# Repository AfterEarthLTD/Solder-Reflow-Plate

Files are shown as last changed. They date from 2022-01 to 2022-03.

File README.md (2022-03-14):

# **Solder Reflow Plate**

###### By AfterEarth Ltd

## As Seen On GreatScott! 

This project has recently featured on a DIY or BUY GreatScott! video.

Check it out here - [The Best way to reflow solder? Hot Plate to the rescue! DIY or Buy](https://www.youtube.com/watch?v=QarizoUnRfk)

## UPDATE!!!

Join the [DISCORD!](https://discord.gg/YzhG6FcCRA)

Checkout the new Ver 3.0 design. Very similar to Ver 2.4 but now comes with ATmega4809 as its availability is much better than the 328p at the moment. Code is still in development but the board designs are available in the Board Versions Folder.

## Versions

- 70mm x 50mm (Ver 2.4)
  - 12VDC (5A Minimum)
  - 5.5mm x 2.5mm Barrel Jack
  - 0.91" OLED Display
  - ATmega328p Microprocessor

- 70mm x 50mm (Ver 3.0) **NEW**
  - 12VDC (5A Minimum)
  - 5.5mm x 2.5mm Barrel Jack
  - 0.91" OLED Display
  - ATmega4809 Microprocessor

## About the Project

Like any good nerd does I've been expanding my hobby horizons.
I've gone from breadboard, to perf board, through-hole, to SMD, ever increasing circuit complexity and improving my knowledge.
But I've become frustrated with the difficulty of SMD soldering.
Regular soldering jogs small components and needs lots of flux.
Hot air damages plastics.
Hot plates are expensive and can be big wastes of space.

*"But you're a nerd"* I hear you cry, *"why don't you DIY a solution?"*.

[Electronoobs](https://www.youtube.com/channel/UCjiVhIvGmRZixSzupD0sS9Q) shows a great DIY solution using an old clothes iron hot plate.
You can watch his video [here.](https://www.youtube.com/watch?v=C7blZigaaaA)
Have a go!

While I love this solution, I wanted to develop something smaller and more permanent.
Hence the Solder Reflow Plate was born, a PCB-based, MOSFET controlled heater, perfect for easily reflowing SMD components giving surprisingly professional results. Furthermore, these results are achieved without breaking the bank or taking up an enormous amount of desk space.

And so, this nerd bestows upon the world his project, fully open-source and hackable.
Here's hoping that it may be used to develop skills, build custom circuit boards, and make quality designs possible to all!

## Purchase

- Register your email address at [www.solderreflowplate.co.uk](https://www.solderreflowplate.co.uk) to know when it is available to buy!
- There is a worldwide shortage of ATmega328p Microcontrollers. I'm currently working on a small redesign for a more readily available chip.
- Purchase will be available soon!

## License

All parts of this project are covered by a [MIT license](LICENSE).
That means it is entirely open-source, so you get access to everything! (just without warranty or liability)
Feel free to download, customise, hack, and commercialise to your nerdy heart's content.

Want the **easy** life?!
**Purchase** the default design above!
Its fully functional, cheaper than customising, and helps to feed the creator's caffeine addiction 🙃

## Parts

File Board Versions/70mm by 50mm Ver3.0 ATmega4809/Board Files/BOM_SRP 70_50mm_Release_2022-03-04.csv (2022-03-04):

ID | Name | Designator | Footprint | Quantity | Manufacturer Part | Manufacturer | Supplier | Supplier Part | Price | Pins | 3DModel | JLCPCB Part Class | Contributor | Resistance | link
1 | 10nF | C8,C10,C12,C13,C14 | C0402 | 5 | 0402B103J500CT | Huaxin S&T | LCSC | C295917 | 0.002 | 2 | C0402_L1.0-W0.5-H0.5 | Extended Part | LCSC |  | https://item.szlcsc.com/15869.html
2 | 4.7K | R3 | R0603 | 1 | AC0603JR-074K7L | YAGEO | LCSC | C144596 | 0.001 | 2 | R0603_L1.6-W0.8-H0.8 | Extended Part | LCSC | 4.7kΩ | https://www.mouser.in/datasheet/2/447/PYu_RT_1_to_0_01_RoHS_L_11-1669912.pdf
3 | ATMEGA4809-AFR | U1 | TQFP-48_L7.0-W7.0-P0.50-LS9.0-BL | 1 | ATMEGA4809-AFR | Microchip Tech | LCSC | C189475 | 4.13 | 48 | TQFP-48_L7.0-W7.0-H1.2-LS9.0-P0.50 | Extended Part | LCSC |  | https://item.szlcsc.com/79128.html
4 | Header-Male-2.54_1x3 | UPDI | HDR-TH_3P-P2.54-V-M-1 | 1 | Header2.54mm 1*3P | BOOMELE | LCSC | C49257 | 0.014 | 3 | HDR-M-2.54_1x3 | Extended Part | 官方封装库 |  | https://item.szlcsc.com/50265.html
5 | K8-5851E-N1_C134191 | DNSW,UPSW | SW-TH_6P-L5.8-W5.8-P2.00-LS4.5-BL | 2 | K8-5851E-N1 | HRO | LCSC | C134191 | 0.203 | 6 | SW-TH_6P-L5.8-W5.8-P2.00-LS4.5-BL | Extended Part | LCSC |  | https://item.szlcsc.com/235656.html
6 | DC-005-5A-2.5 | 12V | DC-IN-TH_DC-005-5A-2.5 | 1 | DC-005-5A-2.5 | XKB Enterprise | LCSC | C381115 | 0.266 | 3 | DC-IN-TH_L14.4-W9.0-H11.0 | Extended Part | LCSC |  | https://item.szlcsc.com/353347.html
7 | 10K | R4,R5,R6 | R0603 | 3 | RTT03103JTP | RALEC | LCSC | C103210 | 0.001 | 2 | R0603_L1.6-W0.8-H0.8 | Extended Part | 立创EDA官方封装库 |  | https://www.mouser.in/datasheet/2/447/PYu_RT_1_to_0_01_RoHS_L_11-1669912.pdf
8 | DSR1M_C908221 | D3 | SOD-123_L2.8-W1.8-LS3.7-RD | 1 | DSR1M | FUXINSEMI | LCSC | C908221 | 0.009 | 2 | SOD-123_L2.8-W1.8-LS3.7-RD | Extended Part | LCSC |  | https://item.szlcsc.com/301422.html
9 | 1nF | C7 | C0805 | 1 | FM21X102K501PXG | PSA(Prosperity Dielectrics) | LCSC | C440004 | 0.008 | 2 | C0805_L2.0-W1.3-H1.3 |  | LCSC |  | https://item.szlcsc.com/373011.html
10 | MM1Z24 | D2 | SOD-123_L2.8-W1.8-LS3.7-FD | 1 | MM1Z24 | SEMTECH | LCSC | C82522 | 0.019 | 2 | SOD-123_L2.8-W1.8-H1.4-LS3.7 | Extended Part | 官方封装库 |  | https://item.szlcsc.com/182946.html
11 | AMS1117-5.0S | 5V | SOT-89_L4.5-W2.5-P1.50-LS4.2-BR | 1 | AMS1117-5.0S | Youtai Semiconductor Co., Ltd. | LCSC | C351450 | 0.088 | 3 | SOT-89-3_L4.3-W2.5-H1.6-LS4.1-P1.50 | Extended Part | LCSC |  | https://item.szlcsc.com/236145.html
12 | 22uF | C3,C5 | C0805 | 2 | CL21A226MAYNNNE | Samsung Electro-Mechanics | LCSC | C602037 | 0.026 | 2 | C0805_L2.0-W1.3-H1.3 | Extended Part | LCSC |  | https://item.szlcsc.com/373011.html
13 | 100nF | C4,C6,C9,C19,C1 | C0603 | 5 | 0603B104K250 | WTC | LCSC | C83054 | 0.004 | 2 | C0603_L1.6-W0.8-H0.8 | Extended Part | 立创EDA官方封装库 |  | https://item.szlcsc.com/362304.html
14 | UMW30N06 | MOSFET | TO-252-2_L6.6-W6.1-P4.57-LS9.9-BR-CW | 1 | UMW30N06 | Youtai Semiconductor Co., Ltd. | LCSC | C369599 | 0.185 | 3 | TO-252-2L-3P_L6.6-W6.1-H2.3-LS10.1-P4.6 | Extended Part | LCSC |  | https://item.szlcsc.com/176608.html
15 | 3K | R1 | R0805 | 1 | RTT05302JTP | RALEC | LCSC | C104211 | 0.003 | 2 | R0805_L2.0-W1.3-H0.6 | Extended Part | layout |  | https://item.szlcsc.com/142685.html
16 | 1K | R2 | R0805 | 1 | CR0805-FX-1001ELF | BOURNS | LCSC | C204136 | 0.017 | 2 | R0805_L2.0-W1.3-H0.6 | Extended Part | LCSC |  | https://item.szlcsc.com/142685.html
17 | LMT85LP | TEMP | TO-92-3_L4.9-W3.7-P1.27-L | 1 | LMT85LP | TI | LCSC | C75856 | 0.559 | 3 | TO-92-3_L4.9-W3.7-P1.27-L | Extended Part | LCSC |  | https://atta.szlcsc.com/upload/public/pdf/source/20180629/C233232_99576441F8ED8E9074FB1575A6BE3592.PDF
18 | 100uF | C2 | CAP-SMD_BD6.3-L6.6-W6.6-LS7.6-FD | 1 | UWT1V101MCL1GS | Nichicon | LCSC | C125975 | 0.113 | 2 | CAP-SMD_BD6.3-L6.6-W6.6-H7.7 | Extended Part | LCSC |  | https://atta.szlcsc.com/upload/public/pdf/source/20210504/9814272B3E8769158D4E334F7BC2BB23.pdf
19 | PESDMC2FD18VB | D1 | SOD-882_L1.0-W0.6-BI | 1 | PESDMC2FD18VB | Shanghai Prisemi Elec | LCSC | C110703 | 0.068 | 2 | SOD-882_L1.0-W0.6-H0.5-LS0.65 | Extended Part | 官方封装库 |  | https://www.littelfuse.com/~/media/electronics/datasheets/tvs_diode_arrays/littelfuse_tvs_diode_array_sp3118_datasheet.pdf.pdf

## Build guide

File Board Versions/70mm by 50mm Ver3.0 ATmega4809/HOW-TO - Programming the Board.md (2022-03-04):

# **Solder Reflow Plate - 70mm by 50mm Ver 3.0 ATmega4809**

## How-To - Programming the Board
This Solder Reflow Plate has been specifically designed to be Arduino based and easily programmed through the Arduino IDE or any other similar environment.
For ease, here is a guide to programming the board via the Arduino IDE.
The ATmega4809 is UPDI programmed. Once the boards arrive and I have experienced this myself I will write up a full guide. In the meantime there are a few good guides out there on UPDI programming from an Arduino.

### Preparation
TBC

### Program
TBC

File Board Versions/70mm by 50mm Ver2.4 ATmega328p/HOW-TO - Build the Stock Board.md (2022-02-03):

# **Solder Reflow Plate - 70mm by 50mm**

## How-To - Build the Stock Board
Building this solder reflow plate is a intermediate level task.
While not overly complicated it still features many small surface mount components and a few polarity sensitive components.
Future versions of the board are being developed to make home building easier to accomplish.

#### Preparations
Firstly, download the Gerber files and Bill of Materials.
While you are there, if you download the Pick and Place Doc you can have select board manufacturers populate the boards for you, normally at extra cost.
Find yourself a board manufacturer and upload the Gerber files and Bill of Materials.
I have used JLCPCB and NextPCB, both have given great quality boards and I've never had a problem with either.
Use the default board settings
- PCB thickness = 1.6mm
- Copper Weight = 1oz
- Material = FR-4
- Colour to your liking
It can make life easier picking up a stencil to help you solder the components on later.
Order as many boards as you like ensuring you order the materials too.
Delivery from China nrormally takes between 2 and 6 weeks.

Some other bits to consider
- You will need to buy a 0.91" OLED seperately. Ebay is normally good for this. Make sure to get the 4 pin I2C version.
- You will need a 12V power supply. Minimum of 5A (take a lot of power to heat to 180C). An enclosed power brick with a 2.5mm inner diameter barrel jack is a good option. Or you can rig one yourself from an open supply like [these](https://www.ebay.co.uk/itm/164636015985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), and a 2.5mm diameter barrel jack adapter. Just be careful as you will be dealing with mains (Live and Neutral) wiring so only do so if you are competent and confident.
- If you picked up a stencil make sure to get some solder paste too.
- Finally, some small hardware is good. The board has holes just bigger than M3 so standard motherboard stand-offs and similar should fit. The board will function without but lifting it off the desk is best.

#### Soldering
I strongly suggest using the stencil and soldering paste to solder this board due to the size of some of the components.
Follow the following rough guidance to get you on your way.
- Place your first board down surrounded by 4 others that are taped to the desk. This holds your working board still.
- Tape the stencil overtop so that the holes align with the pads on your working board. 
- Use a credit card or something flat to push a blob of solder paste over the stencil holes.
- Carefully remove the stencil and clean it.
- Starting with the smaller components, gently place them onto the board following the circuit drawing.
- If you have a working solder reflow board you can now reflow your working board (if any someone would develop one).
- If not, use a fine pointed soldering iron to dab solder the smaller components.
- More heat will be needed to solder the larger components, especially the large tab of the MOSFET.
- Check for good solder joints and that there are no shorts, especially around the microcontroller.
- Move onto the through-hole components. The switches need to be checked for polarity before fitting else they will confuse the software on first start-up. Fit them with the notch pointing towards the OLED.
- Lots of heat will be needed for the ground connections on the input jack.
- Makes sure to solder the temperature chip as close to the board as possible to ensure it best follows the temperature of the plate.

#### Finishing up
Congratulations! You've soldered a thing that will definitely maybe work on the first try!
Give the board a clean with some cleaning solvent or cleaning alcohol.
You can now move onto the programming of the board so open up that document and get cracking.

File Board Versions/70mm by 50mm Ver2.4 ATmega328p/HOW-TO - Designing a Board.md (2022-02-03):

# **Solder Reflow Plate - 70mm by 50mm**

## How-To - Designing a board
Designing a solder reflow board is relatively simple. They consist of
- A low resistance heating element (0.5 - 3ohms)
- A power semiconductor, commonly a MOSFET
- Control circuitry
- Suitably powerful power supply
- Filtering and final touches
Please use the designs provided either in their entirety or as a starting point for your own projects.

#### Heating Element
The heating element on the 70*50mm Ver2.4 solder reflow plate is a 1.4mm single ounce track over a length of 2000mm. It is laid out in a zig-zag grill shape with 0.4mm spacing between lines. This gives the heater element a cold resistance of approximately 0.9ohms and allows it to easily reach a temperature of 200C at only 8.4V. For smaller or larger element sizes these values change so please see the other sized boards for guidance, or experiment for yourself.

#### Power Semiconductor
There are several options for types of semiconductors that could be used in an application such as this, however the most sensible option is a MOSFET.
MOSFETs are easily PWM controlled by low voltage microcontrollers and can provide massive continuous load currents with a very low drain to source resistance and therefore create only small heat losses. The MOSFET chosen for the 70*50mm solder reflow plate is the [UMW30N06](https://lcsc.com/product-detail/MOSFETs_span-style-background-color-ff0-UMW-span-Youtai-Semiconductor-Co-Ltd-UMW30N06_C369599.html) in the package TO-252. This chip is capable of up to 25A continuous current and is plenty strong enough to provide current to the heater element, even at 100% PWM at 12VDC, the board's rated voltage. This MOSFET was mainly chosen for its abundance in the supplier LCSC, as recommended by [EasyEDA](https://easyeda.com/) (online circuit design software) and [JLCPCB](https://jlcpcb.com/) (board manufacturer). However, nearly any TO-252 should be a direct drop-in replacement. Simply ensure that
- The pin layout is the same 
- The continuous current rating is a little over the maximum current your heater element can draw (CurrentContinuous = Vsupply / HeaterResistance)

IGBTs are also a suitable type of semiconductor, though they tend to be more expensive and likely over-specced for this application.

BJTs could also be used but will be more difficult to drive (lower gain values), will come with a much higher heat loss, and require larger sizes to sustain high constant currents. 

I strongly suggest sticking to MOSFETs for this application.

#### Control Circuitry
This is the part of the board that gives you the most freedom. Controlling a MOSFET is as simple as providing a voltage between the gate and source pins greater than that of the minimum threshold but less than the maximum threshold. This function could be achieved by anything from a basic pushbutton and pull-down resistor to a multi-million pound/dollar/euro super-computer. The level of complexity you choose relies heavily on your aspirations for the feature-set.
I designed the 70*50mm solder reflow plate with an Atmega328p as its brain. This is the same microcontroller found on many Arduino and Arduino compatible boards, and so is very easy to program and implement into custom designs. I wanted to include an OLED display, two user push buttons, temperature and voltage sensing, on top of the PWM MOSFET control. Smaller microcontrollers could easily achieve this but the program I wrote could only be accommodated by a microcontroller with larger flash storage.
For ultra-simple control try a 555 timer, a potentiometer, or even a PWM pin on a separate Arduino development board.
For a more complicated build try multiple temperature measurements, splitting the heater element into 'zones' for heater size control, or implementing USB or IoT control for implementation into a production line.

Feel free to use the designs within this Git page to help develop your own solutions. 

More on this solution
- OLED, is the common 0.91" 128x32 pixel display. Connects to the microcontroller via I2C and easily implemented with the [Adafruit SSD1306](https://github.com/adafruit/Adafruit_SSD1306) and [Adafruit GFX](https://github.com/adafruit/Adafruit-GFX-Library) Arduino libraries.
- Temperature Sensing, is done by a [LMT85LP](https://lcsc.com/product-detail/Temperature-Sensors_Texas-Instruments-LMT85LP_C75856.html). This component outputs a voltage inversely proportional to the temperature. This is read by an analogue-in pin on the 328p. While only rated to 150C, it is accurate enough to infer plate temperatures up to 200C with an accuracy of +-10C. Not a high accuracy but cheaper and less complicated than incorporating a thermocouple.
- Voltage sensing, is done by a simple voltage divider that quarters the input voltage. This is also read by an analogue-in pin on the 328p. Resistor tolerance leads to an accuracy variation of +-0.2V from board to board.
- MOSFET PWM, is handled by a PWM capable pin and written to using the analogWrite() Arduino function. This pin is directly connected to the gate of the MOSFET with the only connected components being a 10k pulldown resistor and a filtering capacitor. 

#### Power Supply
Throughout development I have used a large 12V 20A power supply from an old 3D printer and connected using a 6.2mm by 3mm DC barrel jack. This has been perfect for providing a consistent 12V for reliable board testing. The 70*50mm design of board can pull a maximum of 5A, leading to a maximum power use of 60W. This is large but essential in order to provide enough heat to the board under reflow. 
It is important to ensure that the power supply you choose can provide the continuous current required to run your design and over the time period it is required to be run for. 
In my personal experience, lower powered variable bench power supplies may not be capable of providing the current required. In this case consider a different source of power or redesign your board to function at a higher voltage level while reducing the MOSFET duty cycle to keep the heater element power consistent.
Also, your microcontroller will need an appropriate power supply. This can commonly be derived from the 12V or similar main input supply. In my design I have a small SOT-89 5V regulator rated to 1A.

#### Filtering and Final Touches
I've learnt a lot from the development of this board, through its many revisions. Some of my troubles include running out of flash memory, heat spreading to the control circuitry, large voltages seen across the heating element, exceeding fuse current ratings, and so on. Thus, I present to you my lessons in the hope to save you some of the trouble that I faced.
- Choose an appropriate fuse or do not add one to your board. Too weak a fuse can lead to failure due to loss of power under high-current situations. Depending on your power supply, you should be able to rely on their current limiting features or their internal fuses to protect against overcurrent.
- Choose a microcontroller with sufficient flash memory to hold your program. When I added the animations and logos to my program it dramatically increased the program size to over 21kB. If you are designing a very basic control, then you can get away with cheaper/smaller microcontrollers. If you need logos and animations, stick with the 328p or choose an equivalent.
- Preventing heat spreading. You will notice two large slots in the solder reflow plate to limit the heat transfer from the heater element to the control circuit. These are not essential but recommended to improve the life of your components. 
- Large positive voltage spikes can be observed across the heater element when the MOSFET de-energises. The 70*50mm design produced short 10nS peaks of approximately 80V. To protect the surrounding circuitry, it is important to filter this effect. I achieved this by a combination of a 19V Zener Diode and a 1nF ceramic capacitor connected in parallel across the heater element. 
- Temperature sensing is better if part of the heater element copper is extended out to surround the footprint of the temperature sensor. This couples the sensor closer to the element and can result in more accurate measurements.

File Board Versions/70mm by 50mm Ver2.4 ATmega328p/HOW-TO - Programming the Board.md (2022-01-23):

# **Solder Reflow Plate - 70mm by 50mm**

## How-To - Programming the Board
This Solder Reflow Plate has been specifically designed to be Arduino based and easily programmed through the Arduino IDE or any other similar environment.
For ease, here is a guide to programming the board via the Arduino IDE.

### Preparation
1) Download and install the Arduino IDE from the [Arduino Website](https://www.arduino.cc/). The sketch was originally developed on version 1.8.19, though any recent and all future versions of the Arduino IDE should be fully supported.
2) Install the MiniCore additional boards to allow programming of bare Atmega (8bit) chips. Go to 'File->Preferences' and copy the '.json' link below into the 'Additional Boards Manager URLs' textbox. If you have multiple sources, they must be separated by commas. 
https://mcudude.github.io/MiniCore/package_MCUdude_MiniCore_index.json
3) Add the boards to the board manager by searching for and installing MiniCore in 'Tools->Board->Board Manager'.
4) Search for and install Adafruit_GFX and Adafruit_SSD1306 libraries in 'Tools->Manage Libraries'.

### Program
1) Connect your programmer to the ICSP headers on the Solder Reflow Board. This can be any supported USBISP, USBasp, or even an Arduino programmed with Arduino as ISP. If using a commercial programmer make sure your drivers are installed. If using another Arduino make sure to upload the Arduino as ISP sketch and correctly connect the ISCP pins. Use [this](https://docs.arduino.cc/built-in-examples/arduino-isp/ArduinoISP) guide in the Arduino docs if you are unsure.
2) Select the following settings under the 'Tools' tab
- Board -> MiniCore -> Atmega328
- Clock -> Internal 8MHz
- BOD -> BOD 2.7V
- EEPROM -> EEPROM retained
- Compiler LTO -> LTO Disabled
- Variant -> 328P / 328PA
- Bootloader -> No bootloader
3) Set the programmer of your choice, e.g. 'Arduino as ISP (MiniCore)', 'USB ASP', etc, and set the correct port.
4) Burn bootloader to the Solder Reflow Board. This sets fuses and registers correctly so that the sketch needs not directly deal with them.
5) Compile and upload to the Solder Reflow Board.

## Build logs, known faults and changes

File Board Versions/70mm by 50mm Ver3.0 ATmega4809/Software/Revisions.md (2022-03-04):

# **Software Revisions**
###### 70*50mm Solder Reflow plate

## Note
Software not yet complete for this board version. I have several boards on the way, due late March. Software should take a day or two to convert from the original HW Ver2.4 design. It will have all the same feature-set and should be indistinguishable from the original design.

## S/W Rev 1.0
###### H/W Rev 3.0
This is the first complete software revision and has been developed and finalised for hardware version 2.4. The user interface and feature scope of this project was large for the size of board. This initial release contains the following main pages and features...

#### Start-up (contained within setup() function)
- Duration 3 seconds
- Displays Logo
- Displays S/W and H/W versions

#### Main Menu
- Swap display on the left explains user interface
- Temperature and Board Thickness data on the right
- Available temperatures are 140C, 150C, 160C, 170C, 180C, 190C, 200C
- Available thicknesses are 0.4mm, 0.6mm, 0.8mm, 1.0mm, 1.2mm, 1.6mm, 2.0mm
- Push individual buttons to cycle through settings
- Setting saved to EEPROM and loaded from EEPROM on start-up
- Hold both buttons for 100ms, then release, to enter heating mode

#### Heating
- Pauses for 2 seconds before enabling MOSFET, during which time it displays the maximum temperature and board thickness the user has selected
- Displays current input voltage and plate temperature
- Voltage and temperature readings are averaged from 20 consequtive samples
- Heating animation
- Heating process follows the industry standard heating profile, climbing slowly to 75% of the maximum temperature, briefly peaking to the maximum temperature, then beginning cooldown
- PWM value will be held lower if the input voltage falls below a minimum voltage (10.5V)
- Once the plate temperature reaches the user specified maximum this temperature will be held for the board thickness in mm multiplied for 5 seconds. E.g. 2.0mm thickness will be held at peak temp for 10s to allow the peak temp to propogate throughout the board
- If process is not complete within 8 minutes the heating process is cancelled due to 'time out'
- Process can be cancelled by pressing any button

#### Cool Down
- Heating completion triggers cool down screen
- Shows current temperature
- Screen will automatically show completed screen if temperature falls below minimum value (45C)

#### Completed
- Shows that the heating process is complete
- Board now cool enough to handle

#### Cancelled (User Button Pressed)
- Occurs when button pressed during heating process
- Press any button to return to main menu

#### Cancelled (Time Out)
- Occurs when heating process takes longer than 5 minutes to complete
- Press any button to return to main menu
- Suggests using a power supply with a higher maximum current

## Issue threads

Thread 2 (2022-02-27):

[Suggestion] Change microcontroller to RP2040

VinnyCordeiro, 2022-02-27:
The RP2040 is a pretty capable, powerful, cheap, and most important of all, available microcontroller on these shortage times. I understand that the ATmega328P is easier to handle, and that this suggestion would also require a complete rewriting of the code, but not being able to build a reflow plate because of chip scarcity isn't exactly nice, and I don't like the prospect of removing the 328P from an existant Arduino, it's just postponing the problem.

Anyway, thank you for your project! Will build one as soon as possible. :)

adrianmihalko, 2022-02-27:
I would have similar suggestion: what about an ESP8266/ESP32 as controller? Many components are available for it by default (OLED screen, etc.) and it is widely available. For making it even simpler controlling the temperature could be possible in a simple web interface.

KnatteAnka, 2022-02-27:
Maybe even a Wemos formfactor so it can be a shield for either ESP8266 or ESP32 (ESP8266 fits in space for ESP32)

AfterEarthLTD, 2022-02-27:
Thanks all for your input. Hadn't much considered the RPI2040 or the ESP range for that matter. You'll be pleased to know I have already made a small redesign for the ATmega4809 that is/was available a few weeks ago. I placed a production order of 1000 from NextPCB that should be arriving in the next couple of days. If we continue to struggle with microcontroller availability I will certainly redesign for some more available chips! Thanks all

Hartland, 2022-03-03:
The Arduino IDE has the RP2040 in its board library. Very little coding change would be needed to use it.

Technerder, 2022-04-18:
+1 for the RP2040, its easy to use, cheap and seems to have an abundance of stock.

andywarburton, 2022-07-30:
+1 for RP2040. It can also run Arduino code these days so barely any rewriting will be required

LordPinhead, 2022-08-24:
I looked up what the new chip for V3 would cost and I nearly fell of my chair: 18 bucks on LCSC, 21 at Mouser and for others, I didn't even look. A RP2040 would be hard to solder, so why not just put on a Raspberry Pi Pico, I saw projects soldering the PCB directly onto their boards, no headers needed.

platima, 2023-02-05:
Why not use something that's much more open I think Pineseed or Pinenut would be the way to go. Overkill for sure, but less than $1 ea! https://pine64.com/product-category/internet-of-things/iot-wifi-ble/

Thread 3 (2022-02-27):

[Suggestion] will it be able to have an external controller version?

zero-custom, 2022-02-27:
As the video concerned, the lifetime of the reflow plate is a problem.
Thanks to the popularity of the 3d printer, there's lots of cheap heat plate on the market.
So will it be able to be an external controller for the heat plate?
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

AfterEarthLTD, 2022-02-27:
Nice idea. Unfortunately 3D printer plates aren't meant for the high temperatures needed to reflow solder paste. I have had the suggestion of making removable/replaceable plates though. When I know a little more about the longevity I may design this.

speedcrafter442, 2022-02-27:
The longevity of the PCBs will be the biggest issue, most PCBs will have a worktime of only tens of hours. Carl Bugeja has tried to do the same.
https://www.youtube.com/watch?v=fbBXPeC-FPQ https://www.youtube.com/watch?v=ZChSbpBbrt4

AfterEarthLTD, 2022-02-28:
For sure. He was actually my original inspiration for this board.
From my testing so far the boards show little to no damage, especially since they are software limited to 180C. I do hope to make some improvements including better temperature control for future versions.
Stay tuned as I'll write a test sketch to measure and record how many cycles it can withstand before damage occurs.

speedcrafter442, 2022-02-28:
Maybe a thermocouple taped to the bottom of the heater could help

VinnyCordeiro, 2022-03-03:
An alternative would be an external PTC heating plate made out of metal. Already seen some that can reach up to 250°C.

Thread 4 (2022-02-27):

Request: Add schematics

MarkusvonStaden, 2022-02-27:
First of all: Great Work! This is awesome!

I'd like to make a version with USB C.
Could you upload the schematic in EasyEDA format? Currently the schematic is only available as PDF. (Or I am just dumb)
It would save quite some not not having to reverse draw the schematic.

AfterEarthLTD, 2022-02-27:
Have a look in /BoardVersions/70mmby50mmVer2.4/BoardFiles/EasyEDA
There should be a .json that you can import?
Let me know if it works as I've never done an import/export of EasyEDA before

Good luck with the USB C version by the way!! I had planned to do one myself in a few months. Will be interested to see how you get on

MarkusvonStaden, 2022-02-28:
I think this is only the PCB. At least I did not get any schematic out of it.

AfterEarthLTD, 2022-02-28:
Righto, sorted it.
Downloading the project only gave me a Readme.txt file annoyingly.
However, I have exported the schematic in .json form and uploaded under /BoardVersions/70mmby50mm/BoardFiles/EasyEDA
Have a look, you should see both Schematic and PCB there now
Ta

Closed 2022-02-28.

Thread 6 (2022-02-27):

[Suggestion] Reduce number of different components

SR-71x2, 2022-02-27:
The Components 13 (R 3K) and 14 (R 1K) on the BOM only appear once in the schematics to form a voltage divider.
It doesn't seem that there will be much current over this voltage divider, so i'd suggest reproducing it with a 10K and 3x 10K resistors.

That way, all resistors in the project would be 10K's.
Less rails required for a pick&place machine and no way to misplace when manual soldering.

Same method would probaply be possible for some capacitors.
Many of them seem to be only for buffering&filtering purposes without needing to be an exact value.

AfterEarthLTD, 2022-02-27:
Good point! I'll look to change that. Should make things a little easier and cheaper to make.

Closed 2022-02-27.

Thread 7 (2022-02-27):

[Suggestion] Add 24-Pin-Connector for ATX-Power-Supply

SR-71x2, 2022-02-27:
An ATX-Power-Supply already has
- 12V with 10-15A
- 5V with proper filtering
- 3,3V with proper filtering
- An On/Off Switch
- Proper Cooling for high loads

It would be nice to power the whole project directly from a 24-Pin Mainboard Connector.
Just Plug in an old PC's PSU and not worry about Mains-Voltage or blowing your Lab Power-Supply with the load.

The Reflow plate could have a power switch, switching the PSU.

AfterEarthLTD, 2022-02-27:
An interesting idea. I hadn't thought of that. I'd like to make a much larger version for bigger boards in the not too distant future. That will require much more power than the 60W that this already uses. Stay tuned for a bigger version as I will certainly implement some, if not all, of your suggestions.

Closed 2022-02-27.

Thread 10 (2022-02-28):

[Suggestion] Replace Barrel Jack by USB-C

ncx94, 2022-02-28:
I always try to build everything in my toolbox around the USB-C power supplies so I can have one power supply to rule them all  haha :)

If 100W is enough power for the board, I think that is a cool upgrade :)

AfterEarthLTD, 2022-03-01:
Certainly!
I had initially designed around a barrel jack for simplicity to begin with, but be sure there will be a USB C version in the not too distant future.
I plan to work on one myself and I have heard mention of some others forking off the repo and doing the same. Long live open-source!

ncx94, 2022-03-01:
Awesome! In the mean time, I ordered everything to build 3 of then rigth now, I'll rebuild one when USB-C comes in haha.

I would suggest the STUSB4500 chip which would be perfect for that, but unfortunately in these times they are unavailable...

Anyway in my opinion, add USB-C and a replaceable heating part, and you have an amazing product :)

MarkusvonStaden, 2022-03-03:
FYI:
I am starting right now to build a USB C Version. But it might take some time to get it finished, since it is my first real project.
It is not as easy as I initially thought, since USB C PD is designed for 3A, but according to specification it should also handle 5A.
USB C doesn't have a 12V Level, only 15V, so we get a higher current. I will have to do some testing...
I think, I might use the 15 or 20V line and a step-down circuit.

PS: Maybe we could do a discord channel or something, where we can communicate with each other?

martinlanza, 2022-03-03:
I'm not sure USB is a good option

Most notebooks these days run off 20v - banggood has adaptors for all of
them to a barrel plug - would be handy to be able to use the notebook PSU

On Thu, Mar 3, 2022 at 10:09 PM Markus von Staden ***@***.***>
wrote:

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

ncx94, 2022-03-03:
Awesome @MarkusvonStaden !
I would also make the electronics and heating plate separate as well, while being at it haha!
Tell me if I can help you.

Regarding 12V, yes not all usb-c pd supplies have that option, don't think it's actually part of the standard. However that shouldn't be a problem in my opinion, we could probably make it work regardless of the power input (in a limited range, like 12-20v) by measuring the actual Vin and adapting the pwm settings around the input voltage.

Totally in for the discord channel!

@martinlanza In my opinion, USB C is way more common nowadays than barrel connectors.. However I think we could use both options and combine them on the pcb so anyone can choose the preferred one

axoulc, 2022-03-03:
Hi, I started to fork this project in order to make USB-C board with STUSB4500 and an other mcu (STM32G030F). The Schematic is already done. We can work together if you want.
Sincerely

ncx94, 2022-03-03:
> Hi, I started to fork this project in order to make USB-C board with STUSB4500 and an other mcu (STM32G030F). The Schematic is already done. We can work together if you want. Sincerely

Awesome! :)
The STUSB4500 is definitely a top notch option, but pretty hard to get these days unfortunately! Why did you change the MCU?

If we can get the board with both USB-C and Barrel Jack, external heater board, and maybe profile automatic heatup, I think it's awesome

axoulc, 2022-03-03:
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

I prefer to change the mcu to have availability in the near future. This component is smaller, more powerful and cheap.
Keep the Barrel Jack will not be a problem.
For USB PD IP2721 can also be a solution.

ncx94, 2022-03-03:
I see :)
There have been multiple discussions around the MCU change, mostly because of the Atmega328p availability, I think it would be great if everybody settled on one choice so we can all go in the same directions hahaha

Yes, IP2721 does work too :)
I'd rather use brand name parts though, had too much issues with performance and availability in the past with obscure components haha

axoulc, 2022-03-03:
My choice of MCU will not be objective I am a  STM32 fan  ;)

ncx94, 2022-03-03:
Haha don't worry we're in the same boat here haha!
But sometimes overkill isn't the best way to kill hahah

MarkusvonStaden, 2022-03-03:
Oh, I see, we get quite a big community here :D
I used the IP2721 in my Design, since I have a bunch of them around.
I plan to finish it today, so I can order the first PCBs to test.

AfterEarthLTD, 2022-03-04:
Wow guys!
This sounds great. I love the idea of making it USB-C powered.
You'll certainly need a well specced USB PD capable of 60W or more at 20V for the same size board. Also, consider increasing the capacitance to even out the current draw when the MOSFET is being pulsed.
Look forward to seeing what you come up with.

Also, I've created a Discord for SR Plates. https://discord.gg/T9dxeRmY Please feel free to join send invites, create a channel and manage your project through that if you like.

Alchme, 2022-03-14:
First comment on the project. Just wanted to add the new Discord link that never expires here:

https://discord.gg/YzhG6FcCRA

AfterEarthLTD, 2022-03-14:
Done, well spotted, thanks

Johaan1314, 2022-05-30:
Hi,

Added my implementation of IP2721_MAX12. I tried to use back similar components to reduce BOM list. Any comments?

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

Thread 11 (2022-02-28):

Code recurses

bhelterline, 2022-02-28:
I took a brief look at your software and it appears that your main_menu() function calls itself in several places under the proper circumstances.  I would suggest your model your code like a state machine instead.  These small MCUs do not have the resources to recurse without overrunning the stack and crashing.

AfterEarthLTD, 2022-03-01:
Good point!
This is my first large-scale program so I'm not surprised there is something wrong.
I'm familiar with state machines so I will look into converting it.
Thank you

bhelterline, 2022-03-01:
I also noticed that your chosen MOSFET is not a "logic level" version but you are driving it directly from the arduino pin.  This means the MOSFET will not be fully on with a Vgs = 5V.  Much better to choose a better MOSFET.  Search for "logic level MOSFET" and the datasheet needs to specify Rds or Ron at Vgs = 5V, not 10V.

AfterEarthLTD, 2022-03-02:
Nice! To be honest, I wasn't aware Logic level MOSFETs existed. I simply checked that the MOSFET I chose had a sufficiently small Vgs (1.2v min, 2.5v max). Though I can see now how you can give it more gate voltage to achieve a lower internal resistance. I'll certainly implement that for later versions of Ver 3.x (Ver3.0 is already on order so that makers can actually by something!)

Thank you for your expertise!!

ShawMerlin, 2022-03-08:
Here is a good video on using Logic Level Mosfets.  It's not a one stop solution for MCU's.

https://www.youtube.com/watch?v=56p3_aORiJ0

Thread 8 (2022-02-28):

Suggestion : can you increase the size of the board?

Habibjackson, 2022-02-28:
The size of the board is small, can you increase the size? So we can work with larger PCB.

AfterEarthLTD, 2022-02-28:
Hi, I plan to in the future.

I'm also planning to use grub screws instead of motherboard standoffs as this should allow boards to overhang without being obstructed.

Stay tuned to see what I get up to

Closed 2022-02-28.

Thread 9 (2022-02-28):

FR4

Rudis1261, 2022-02-28:
Looking forward to making one of these myself, is it necessary to order a higher temp grade FR4? The price seems to shoot up when you do so 😱

Would TG150-160 be ok?

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

BackLogers, 2022-02-28:
I have a similar question and doubts, JLCPCB only offers the TG130. What does the durability look like? Is the temperature of 170 degrees achievable without damaging the surface?

narendok, 2022-02-28:
same i doubt, In india, pcbpower offer 130, 150, >170 option , should i go 170 or 130-140 is fine ?

AfterEarthLTD, 2022-02-28:
Hi all,
All of the boards I have ordered and tested have been TG130. I wanted to make the boards as accessible and affordable as possible, hence staying away from exotic materials and aluminium.
The boards are limited to 180 degrees and stay there for only a short time. During my testing they show no damage, especially with the black silkscreen.
I imagine higher TG may last longer, but is not necessary.

Hope that helps
Chris

narendok, 2022-02-28:
Nice, Thank you so much for sharing such amazing work, I'm trying one for sure for my startup. God bless you.

Rudis1261, 2022-02-28:
@AfterEarthLTD  Awesome thanks for confirming, I am happy with going the standard as well then :grimacing:

Closed 2022-02-28.

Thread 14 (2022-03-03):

Mount components on bottom

lsadehaan, 2022-03-03:
Hi, this is a very cool project! I was just wondering, would it be possible to mount the components on the bottom and have the LCD and buttons on the side below the board. That way the top would be flat and make it much easier to place the piece you are soldering on top - especially if it is a large piece.

lsadehaan, 2022-03-03:
Perhaps separating the heating board into a separate board that can be mounted with risers on top of the controller board would be even better - then one could replace the heating board if needed or even have different size heating boards.

martinlanza, 2022-03-03:
I really like that idea - and make heating boards available as spares

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

lsadehaan, 2022-03-03:
A small adaptation to the current design might be possible, with solder points for adding an external/mounted heating board. Then one can use the base unit alone, or expand it with an external heating board if you like.
The current design is nice for small parts and probably many people won't need anything more initially.

AfterEarthLTD, 2022-03-04:
Hi, nice ideas!
Putting components on the bottom and having the entire top as a heater could work very well. I think I'd have to limit the max heating temp for low temp paste to make sure it doesn't melt the control solder of damage the components over time.

The detachable board is a good idea. A few people have suggested similar ideas. I'll certainly look into it as its a popular request.

I plan to make a larger board in the not too distant future so I'll take this all into consideration.
Thank you

lsadehaan, 2022-03-04:
> having the entire top as a heater could work very well

I wasn't really thinking about increasing the size of the heater on top since it could damage components on the bottom, but if that could work it would be interesting. The reason for moving the components to the bottom is just so you have a completely flat element you can put a larger piece on top of - lets say you have a very large piece and you want to heat the middle part of it, with the current design that's not possible. For this to work the risers would need to be flush and not stick out the top.

AfterEarthLTD, 2022-03-04:
Oh I see!
I like that.
On the version I have purchased to sell I have sorted out grub screws that sit flush with the top, therefore opening up the sides and the bottom. But you're right, if everything was on the bottom it would be easier to flow bigger boards.

lsadehaan, 2022-03-04:
Yes, I came across your design from a youtube video from Scott ( [GreatScott video](https://www.youtube.com/watch?v=QarizoUnRfk) ) where he compared your design to a really tiny commercial unit. When he was showing how he was working with a big board for each unit it was clear that the commercial unit, even though it is much smaller, is much easier to handle since you can just place the board on top. My take-away was that the DIY version would be way superior to the commercial one, if only you could do the same.

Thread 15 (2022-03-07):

The link on BOM is not matched to Name

doskoi, 2022-03-07:
The most link of capicator on BOM is wrong?

e.g.
1nf link to 10nF ±10% 250V
but 22nf is the same link.
100nf to 2.7nf

Also happens on other components, please check and update the links.

Not sure which is correct, title or link.

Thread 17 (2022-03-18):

MOS未完全导通

yishunzhikong, 2022-03-18:
原理图中你使用单片机的GPIO直接驱动MOS，要让MOS完全导通，通常需要VGS>10V，然而大多数单片机IO电压只有3.3V或者5.0V，所以建议添加MOS驱动电路，例如UUC27517或者三极管图腾柱电路。
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

sissoux, 2022-04-26:
I agree, this MOS really needs a driver !

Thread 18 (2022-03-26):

Missing SW1 SW2 silkscreen

Rudis1261, 2022-03-26:
Hi hi, not sure if this has been fixed in more recent board versions. PCBWay sent me this when I ordered SMT assembly:

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

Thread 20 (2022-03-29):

Using a AtMega328p from another arduino device

Rudis1261, 2022-03-29:
So after some research, I found how to set the 329p fuse to use the internal clock in case you want to repurpose an Arduino with a suitable chip like a lilypad.

You will need to hook up the Arduino on the ICSP headers, and use another Arduino programmed as an Arduino as ISP to program the target 328p board.

Using this command you can set the fuse to tell the Arduino to use the internal clock:
```shell
~/AppData/Local/Arduino15/packages/arduino/tools/avrdude/6.3.0-arduino18/bin/avrdude.exe -PCOM8 -v -patmega328p -cstk500v1 -PCOM8 -b19200 -C avrdude.conf -U lfuse:w:0xF2:m
```

The command broken down:
```shell
# The path of your avrdude.exe file
~/AppData/Local/Arduino15/packages/arduino/tools/avrdude/6.3.0-arduino18/bin/avrdude.exe
```

```shell
# The COM port where the Arduino as ISP can be found
-PCOM8
```

```shell
# Verbose output
-v
```

```shell
# The target chip
-patmega328p
```

```shell
# The programmer avr should use
-cstk500v1
```

```shell
# The baud rate as set in the Arduino as ISP sketch uploaded to the programming Arduino
-b19200
```

```shell
# The avrdude.conf, this may not be in the same directory as the command.
-C avrdude.conf
```

  -U lfuse:w:0xF2:m

doskoi, 2022-03-31:
Thanks for the useful material, this doc do the same thing in another approach https://docs.arduino.cc/built-in-examples/arduino-isp/ArduinoToBreadboard/

doskoi, 2022-04-01:
Or from the comments inside the source code

To program
 *  1) Select the following settings under (Tools)
 *      Board->Minicore->Atmega328
 *      Clock->Internal 8MHz
 *      BOD->BOD 2.7V
 *      EEPROM->EEPROM retained
 *      Compiler LTO->LTO Disabled
 *      Variant->328P / 328PA
 *      Bootloader->No bootloader
 *  2) Set programmer of choice, e.g.'Arduino as ISP (MiniCore)', 'USB ASP', etc, and set correct port.
 *  3) Burn bootloader (to set fuses correctly)
 *  4) Compile and upload

doskoi, 2022-04-01:
I was upload without set fuse nor use minicore to set internal clock but just sodering chip on this board,
Then I'm using breadboard with DIP 16M external clock attach to XTAL1 and XTAL2 (PIN7, 8), after this I can comminucate with 328p by programmer again.

simonstrachan, 2023-08-23:
I had my boards assembled with the Atmega already on them. Is there a way to do what GreatScott did in his video with a function generator? I can not seem to be able to get the bootloader to sync. Is it only possible to do it with an external clock or taking one from an existing Arduino?

doskoi, 2023-08-29:
You need to follow the setup at above to enable built-in clock.
> Clock->Internal 8MHz

For your circumstance, you need a external clock to do this setup work. after that, you won't need external clock.

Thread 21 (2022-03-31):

Licence for board designs

Computroniks, 2022-03-31:
I note that the repository's licence is the MIT software licence but does this cover the schematics as well? The reason I ask is that the MIT licence is normally used for the software side of things with a different licence being used for hardware. Also, great work on the project.

piotrkochan, 2022-07-03:
Everything is under MIT if not specified elsewhere. Just steal it, make your own version and earn money.

Closed 2022-10-02.

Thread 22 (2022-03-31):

Issue with debouncing

ViggoAvatar, 2022-03-31:
There seems to be some kind of issue with the code not properly running with the current debouncing method. in order to get the heater to heat i need to hold both buttons while it's heating, letting go will instantly cancel the process and the animation will stop where it left off, been snooping around in the code for a bit but first I'm checking whether or not i made a mistake with the hardware.

toto99303, 2022-04-17:
> There seems to be some kind of issue with the code not properly running with the current debouncing method. in order to get the heater to heat i need to hold both buttons while it's heating, letting go will instantly cancel the process and the animation will stop where it left off, been snooping around in the code for a bit but first I'm checking whether or not i made a mistake with the hardware.

It's not only you. I have exaclty the same issue and I thought my board has problems. Then I recreated the whole thing on a breadboard using brand new Arduino Pro Mini 3.3V 8Mhz and it's behaving exactly the same. There's definetely a problem with the code.

ViggoAvatar, 2022-04-17:
> > There seems to be some kind of issue with the code not properly running with the current debouncing method. in order to get the heater to heat i need to hold both buttons while it's heating, letting go will instantly cancel the process and the animation will stop where it left off, been snooping around in the code for a bit but first I'm checking whether or not i made a mistake with the hardware.
>
> It's not only you. I have exaclty the same issue and I thought my board has problems. Then I recreated the whole thing on a breadboard using brand new Arduino Pro Mini 3.3V 8Mhz and it's behaving exactly the same. There's definetely a problem with the code.

Good to see im not the only one with the problem, I have a quick fix, I'll make a branch for it. It still has problems properly dealing with double press.

toto99303, 2022-04-17:
Thanks! Did you also had issues changing temperature with Up/Down buttons?
I'll try your version now.

toto99303, 2022-04-17:
Works great, thank you very much @ViggoAvatar !

vonryan123, 2022-04-21:
4809 Version tested working!
https://github.com/vonryan123/Solder-Reflow-Plate

deafloo, 2022-05-03:
@vonryan123 would you mind creating a pull request for your 4809 software?

vonryan123, 2022-05-03:
> @vonryan123 would you mind creating a pull request for your 4809 software?

I don't really know much about code nor pretend to, if I understood what a pull request was or why its needed I would.

deafloo, 2022-05-03:
well done! With this pull request, the maintainer can copy your code in his empty directory and it is much easier to find for others

JoeLutz11, 2023-06-13:
Turning the switches by 180° solved the Problem for me, the little notch on the buttons has to be on the left side.

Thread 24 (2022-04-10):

Concerning the PCB melting issue

wswongat, 2022-04-10:
I would like to know which material type is using in this project? Does it start to melt for long run?
I did some searching on JLCPCB and it seems that the default material of 2 layers PCB is FR-4 Standard Tg 130-140.
I know the maximum temperature setting is 180°C from the source and it should use FR-4 with Tg 155 or above.

Anyway, thanks for sharing this project!

Wilson

ShawMerlin, 2022-04-10:
PCBWay will do TG150-TG160 for no extra charge but they have a higher shipping charge than JLCPCB.

If you are in the US then OSHPark has a standard of TG180 and even though they are pricier, they have amazing quality with free shipping.

https://www.reddit.com/r/PrintedCircuitBoard/comments/9bt5ed/how_come_jlcpcb_be_so_cheap_compared_to_others/

fennectech, 2022-04-21:
In a revision. The PCB could be a removable module that plugs into the controller.  Allowing replacing the heater component of the PCB without replacing the entire board and treating the heater as a wear part

EllaBarker, 2022-06-06:
Numbers?
Other projects failed because of this issue.

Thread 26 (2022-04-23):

Temperature overshoot

ManCloud, 2022-04-23:
When I set the temperature to 140°C the PCB ramps up to 225°C (even starting to smoke).

Is this intended?

I measured with NTC probe and IR-Thermometer.

Scrapz, 2023-02-18:
I had this too - I've noticed that the temperature shown on the screen does not reflect the actual temperature, by quite a bit (ie; shows 60 deg on the screen when the board is 100). I didn't let it get up to 225 though, I stopped it when it hit 180. As a result I'm not comfortable with using this for anything.

Is there something in particular that we can start to look at?

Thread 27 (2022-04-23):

Pretty hot C2

ManCloud, 2022-04-23:
When the plate heats up the 100uF capacitor C2 gets pretty hot.

NTC probe says something around 110°C...
This is pretty near the max temperature the cap is rated for.

I guess it's caused by reactive power die to the PWM. I measured with an oscilloscope and got drops of approx 1V @ 31.5 Khz.

Maybe this can be matched by a Coil?

vamatis, 2022-04-23:
Noticed the same here...

Robert-Such, 2022-09-28:
I am seeing temps getting closer to 130°C for C2...

Scrapz, 2023-02-18:
I just built the v2.4 board and noticed this myself. Did anyone have a fix for this?

brettski74, 2023-02-18:
There are a number of issues with this design. One is that the input capacitance is woefully low. This results in high ripple currents into and out of the input capacitor. I wouldn't recommend trying to smooth this out with an inductor. The currents are relatively large and so the inductance you'll need will also be relatively large and likely result in large voltage spikes without adequate capacitance to absorb them. What this really needs is a *lot* more input capacitance - somewhere in the realm of 20-40x more. There's not really a way to retrofit that onto this board without a redesign of the layout.

Curiously, I think a lot of us having been building the v3.0 hardware design over the last year and the most common firmwares for that didn't have the code in there to modify the timer/counter control registers on the atMEGA4809 and bump up the PWM frequency. As a result, we were using the default PWM frequency of 490Hz. At those frequencies, the power dissipation in the input capacitor is minimal and you could leave you finger on it for the entire reflow cycle. The input capacitors aren't really doing much for you at either frequency, so I'd suggest that your best option is to move to a better design. There is one by [DerSpatz](https://github.com/DerSpatz/PCB-reflow-solder-heat-plate) that's been around for a while. If you really want to stick with the v2.4 hardware, then I'd say your best workaround is to lower the PWM frequency by commenting out the TCCR2A and TCCR2B lines (148/9) in the setup() function and make sure your power supply can handle something like 15A of load current.

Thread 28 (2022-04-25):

Request update on software for version 3 board

vjkolaventy, 2022-04-25:
Hi

I got a sample PCB of version 3 board. Can you please let me when you can release the software for this board? If not at least let me know the pin numbers and how to enable the fast PWM. There is something mentioned on pin swap in MegacoreX for ATMega4809. So I am not sure if I should be using the pin numbers on the chip or the pin number as per MegacoreX.

Regards
Vijay

platima, 2023-02-05:
https://github.com/brettski74/Solder-Reflow-Plate/tree/main/Board%20Versions/70mm%20by%2050mm%20Ver3.0%20ATmega4809/Software/SW1.0_HW3.0_70by50mm

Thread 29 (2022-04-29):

Does the OLED display require pullup resistors?

vjkolaventy, 2022-04-29:
Hi

I am unable to make the OLED display work. I noticed that there are no pull up in schematic for the V3.0 board. Can you please advise if I need to add 4.7K or 10K pullup resistors to get the OLED display to work?

Regards
Vijay

deafloo, 2022-05-03:
I have a v3 board with working OLED. No pull up resistors required, just solder the 4 OLED-pins to the PCB.

vjkolaventy, 2022-05-03:
Florian
Can you please share your code for the v3.0 board? The board worked for me randomly once after trying many times but I don’t know what actually worked. I am not even able to make just the OLED to work.
I doubted the pin configuration of MegacoreX and used the blink code on the mosfet pin as suggested by MCUdude and it worked.
If you cannot share the code, can you please share simple code to check the OLED.
Regards
Vijay

deafloo, 2022-05-03:
Hi
I would try following steps:
- grab an arduino and check if the oled itself is working. (follow a tutorial like https://startingelectronics.org/tutorials/arduino/modules/OLED-128x32-I2C-display/)
- check your soldering. I had to touch up the mcu several times until every pin was connected.
- plug in 12V and measure the voltage at the +5V and 0V pin on the right side. It should obviously say 5V
- flash v3 code from #32. You will see the menu as soon as you power it on

I can assure you the MegacoreX pinout is correct. I know the numbers are different from the datasheet but it uses internal addresses so just dont touch it.

Hope that helps

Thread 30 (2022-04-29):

[Suggestion] Replacable heating surface

fennectech, 2022-04-29:
If you have the hot plate connected to the controller board with removable bolts that conduct the power.  This would permit replacing the hot plate without resoldering the whole thing making it much more reusable.  Treating the heating surface as a wear part

fennectech, 2022-04-29:
The idea is you have two pcbs.  The controller board with several of these
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.  You then attach the hot plate and screw it down with these lugs and these lugs carry the power and signals to and from the hot plate PCB.  This permits basicly zero soldering to the heat plate PCB.  Raising it off the surface of the table for improved thermal isolation and an easily replacable wear part that can be ordered from any PCB manufacturer without actually replacing the controller module.

fennectech, 2022-04-29:
This would make maintaining the product MUCH cheaper and easier.  Also allowing alternative heat surface designs to be used without replacing the expensive parts like the display and controller and power regulation stuff

ChuckYYC, 2022-06-19:
This would be very good improvement in the overall design.

LordPinhead, 2022-08-24:
I throw in my 2 cents: Use a silicon heating element like 3D printerbeds have and 5mm Aluminium plates, you control the heating element with a Mosfet and multiple sensors. Aluminium is a great conductor and when you use Airplane style Aluminium (AlMgSi0.5), it wont bend or warp that easy. I've bought a 235x235mm plate for 12 Euros, the heating pad was 19 Euros, the Mosfet was like 5 Euros. Combined with this project, you have a replaceable heating bed.

This PCB is great for small repairs though, like removing an HDMI port and resolder a new one, you don't need big space for it.

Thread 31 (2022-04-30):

[Suggestion] Isolated frame around heating surface

Hermy1902, 2022-04-30:
I would suggest, that you add a border around the heating surface, with a gap, like you have to the PCB part.
So, you are less likly to hurt yourself when you try to grap the PCB.

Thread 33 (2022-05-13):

[Question - higher heating power]

SleXx88, 2022-05-13:
I have created a larger heating surface, the total length is 3800mm, width 1.4mm and spacing 0.4mm.
My power supply can supply max 30A at 12V. The calculated resistance at 25 degrees is 1.36 ohms, then at 12V it is 8.8A. The board is therefore larger and gets about 220 degrees hot. As soon as I put a PCB on the plate it takes longer to heat up due to heat dissipation, which is normal. But I do not get to 200 degrees. How can I adjust my design so that the plate has a higher performance?
Is it useful to reduce the board resistance by making the trace wider? What would be useful here?

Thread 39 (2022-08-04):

Please provide the code for V3.0

hemangjoshi37a, 2022-08-04:
Please provide the code for V3.0

platima, 2023-02-05:
https://github.com/brettski74/Solder-Reflow-Plate/tree/main/Board%20Versions/70mm%20by%2050mm%20Ver3.0%20ATmega4809/Software/SW1.0_HW3.0_70by50mm

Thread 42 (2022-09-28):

No mention of compatible solder pastes in main readme

Robert-Such, 2022-09-28:
I just built one of these reflow plates and am pretty excited about it since I have not used the reflow technique before.  My understanding is that solder pastes have different reflow curves and therefore reflow ovens will generally be programmed in order to perform against that specified curve.  On the other hand it appears that this hot plate comes set with a default reflow curve in mind however I am unsure as to what solder paste this curve belongs to.

Could we add a quick mention somewhere in the readme for some pointers on solder paste recommendations?

Johaan1314, 2022-09-29:
why don't you just enter the figures yourself to suit your solder paste?

//Heater Control Variables
  /*  Heater follows industry reflow graph. Slow build-up to 'warmUp' temp. Rapid ascent
   *  to 'maxTemp'. Then descent to room temperature.
   */
  //byte maxTemp; //Declared in function call
  byte maxPWM = 0.70 * maxTemp; //Temperatures (in PWM / 255) influenced by paste temperature
  byte warmUpTemp = 0.75 * maxTemp;
  byte warmUpPWM = 0.72 * warmUpTemp;
  float t; //Used to store current temperature
  float v; //Used to store current voltage
  byte pwmVal = 0; //PWM Value applied to MOSFET
  unsigned long eTime = (millis() / 1000) + (8*60); //Used to store the end time of the heating process, limited to 8 mins

Robert-Such, 2022-09-29:
I really appreciate the response but I think we are talking about two different things here.  Looking back I see that I should have clarified my original question a bit better...

Essentially I am more concerned with staying within the hardware limitations of the device (i.e. thermal limits of the pcb, components etc) rather than just changing values in software.  For example the data sheet for ChipQuik SMD291AX solder paste recommends a reflow curve that peaks at 235C.  Would this solder paste be ok to use or could it possibly damage the device or cause accelerated wear & tear?

I see the design notes in this repo mention that although 150C is officially the rated range for the LMT85LP temp sensor it should still maintain reasonable accuracy up to 200C.  Also, In the handful of times I have used my device today (with default reflow curve) it appears that the capacitor C2 is reaching 130C during operation despite being designed for temperature ranges up to 105C.  In this case would a solder paste with a reflow peak of 235C be a good idea or not really?

Johaan1314, 2022-09-29:
I see.. you can try switching to a low melting point solder if you are worried, but if you are just using it once in a blue moon (like I am), I won't be too worried about the peak temp which just lasts a very short time.

If you are using it much more often, this PCB hotplate probably won't last. I suspect the PCB will fail and delaminate first before the components get fried.. but that's just my guess..

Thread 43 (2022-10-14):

Heating board/component board

JamesHauser1, 2022-10-14:
Chris--Just an idea. Why not have the component board detachable from the heating board. That way you can replace the heating board if need be.

aaronse, 2022-10-14:
Hey @JamesHauser1, have you checked out the discord server https://discord.com/channels/949124073164787732/949124076142751777 ?  Looks like bunch of folks have made progress on decoupling the controller from the hot plate.

There's so many forks of this project, but hard to tell who's done what, and unfortunately pull requests don't seem to be getting merge into the main branch.

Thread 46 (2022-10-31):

[Suggestion] Use same common footprints as much as possible.

f5AFfMhv, 2022-10-31:
Currently there are several different smd footprints used for capacitors. In my opinion it would be better to use one common footprint for most values. I think 0805 is most popular, also 0603 parts can be easily soldered to 0805 footprint pads.

FedericoBaccini, 2023-03-01:
I just made a new version using only R and C with 0805 package, using also kicad

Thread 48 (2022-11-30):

Burning bootloader with Arduino gives me Device signature error

wsiffer, 2022-11-30:
I ordered these boards from JLCPCB pre-soldered with the 328p. I am trying to burn the bootloader with an arduino and have all the pins wired directly from the UNO iscp pins to the reflow ISCP pins.

Has anyone else got this issue?
here is an image:
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

JoeLutz11, 2022-12-22:
Yes Got the same issue but don't know how tho solve it

Johaan1314, 2022-12-23:
I think you need a crystal oscillator if you are burning it for the first
time. Check out the video link in the main page.

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

wsiffer, 2022-12-27:
I actually found a fix by making sure to wire properly. I did blow up a chip trying to give it a clock signal. I ordered 5 and successfully programmed the next 4 after I figured out the wiring

Closed 2022-12-27.

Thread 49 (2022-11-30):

Software does not advance

Mutilo, 2022-11-30:
Hi!

When I start the solder plate reflow (70mm by 50mm Ver2.4 ATmega328p), it shows this message on the OLED screen and it doesn't do anything else:
Solder Reflow Plate
S/W V1.0
H/W V2.4

I can't find where the problem is

Scrapz, 2023-02-19:
Try putting in the buttons around the other way. Of the 6 pins, 4 of them are connected to one side.

There's a little notch on the button, make sure it's pointing to the left, towards the OLED/ATmega on both buttons.

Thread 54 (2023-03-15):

Any plans to design bigger boards?

ArkBrj, 2023-03-15:
Hello,
Looks like this is a great project and I am considering making one for myself.
However, I actually need a bigger heating element, like 100x70 or so.
I am thinking about modifying your design, but that would put this project on hold for some time.
I guess there might be some complications related to uneven temperature distribution and such, so it might be not a straightforward change.
I wonder if you have any plans to do it yourself.

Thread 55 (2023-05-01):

Lower temperature control

chalmers4c, 2023-05-01:
Hello,

I am interested in repurposing this for some wet-lab stuffs, we have limited space inside a box, and inside that box, I want to heat up a vial of liquid to 37 degrees Celsius mostly or higher but like 60 degrees celsius or something like that. I am not a software/computer scientist so i am wondering if it is possible to change the temperature setting to lower or allow user to edit?

Thanks.

transistorsion, 2024-01-06:
Hello yes you can do that open the code and got to the line byte maxTempArray
and add the temperate you want and upload your new code i show you example

byte maxTempArray[] = { 60, 70, 80, 90, 100, 110, 120, 130, 140, 150, 160, 170, 180 };
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

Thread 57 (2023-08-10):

If anyone wants to build and compile with the atmega4809 chip.

gotnull, 2023-08-10:
Got this working with an atmega4809 with the following sketch:

To prepare:

Install MiniCore in additional boards; (copy into File->Preferences->Additional Boards Manager URLs)
https://mcudude.github.io/MegaCoreX/package_MCUdude_MegaCoreX_index.json
Then add MiniCore by searching and installing (Tools->Board->Board Manager)
Install Adafruit_GFX and Adafruit_SSD1306 libraries (Tools->Manage Libraries)
To program:

Select the following settings under (Tools)
Board->Minicore->Atmega4809
Clock->Internal 16MHz
BOD->BOD 2.6V
EEPROM->EEPROM retained
Pinout->48 pin standard
Reset pin->Reset
Compiler LTO->LTO Disabled
Bootloader->No bootloader
Compile and upload using UDPI programmer or (FT232R with RX, TX and 1K resistor between them, then hookup RX to UDPI and GND to GND)
If using FT232R then use the following commands to a) ping b) write to the microcontroller and the Python pymcuprog library (pip3 install pymcuprog)
a) pymcuprog ping -d atmega4809 -t uart -u /dev/tty.usbserial-XXXXXXXX
b) pymcuprog write -f SW1.0_HW3.0_70by50mm.ino.hex -d atmega4809 -t uart -u /dev/tty.usbserial-AH0014LK

 /* Solder Reflow Plate Sketch
 *  H/W - Ver 3.0
 *  S/W - Ver 1.0
 *  by Chris Halsall
 */

/* To prepare
 * 1) Install MiniCore in additional boards; (copy into File->Preferences->Additional Boards Manager URLs)
 *     https://mcudude.github.io/MegaCoreX/package_MCUdude_MegaCoreX_index.json
 * 2) Then add MiniCore by searching and installing (Tools->Board->Board Manager)
 * 3) Install Adafruit_GFX and Adafruit_SSD1306 libraries (Tools->Manage Libraries)
 */

/* To program
 *  1) Select the following settings under (Tools)
 *      Board->Minicore->Atmega4809
 *      Clock->Internal 16MHz
 *      BOD->BOD 2.6V
 *      EEPROM->EEPROM retained
 *      Pinout->48 pin standard
 *      Reset pin->Reset
 *      Compiler LTO->LTO Disabled
 *      Bootloader->No bootloader
 *  2) Compile and upload using UDPI programmer or (FT232R with RX, TX and 1K resistor between them, then hookup RX to UDPI and GND to GND)
 *  3) If using FT232R then use the following commands to a) ping b) write to the microcontroller and the Python pymcuprog library (pip3 install pymcuprog)
 *    a) pymcuprog ping -d atmega4809 -t uart -u /dev/tty.usbserial-XXXXXXXX
 *    b) pymcuprog write -f SW1.0_HW3.0_70by50mm.ino.hex -d atmega4809 -t uart -u /dev/tty.usbserial-AH0014LK
 */

#include <SPI.h>
#include <Adafruit_GFX.h>
#include <Adafruit_SSD1306.h>
#include <EEPROM.h>
#include <Bounce2.h>

//Version Definitions
static const PROGMEM float hw = 2.4;
static const PROGMEM float sw = 1.0;

//Screen Definitions
#define SCREEN_WIDTH 128
#define SCREEN_HEIGHT 32
#define SCREEN_ADDRESS 0x3C   //I2C Address
Adafruit_SSD1306 display(SCREEN_WIDTH, SCREEN_HEIGHT, &Wire, -1); //Create Display

//Pin Definitions
#define mosfet PIN_PC3
#define upsw PIN_PD0
#define dnsw PIN_PD1
#define temp PIN_PF5 // MegaCoreX board required
#define vcc PIN_PF3 // MegaCoreX board required

Bounce2::Button upButton;
Bounce2::Button downButton;

//Temperature Info
byte maxTempArray[] = { 140, 150, 160, 170, 180 };
byte maxTempIndex = 0;
byte tempIndexAddr = 1;

//Voltage Measurement Info
float vConvert = 52.00;
float vMin = 10.50;

//Solder Reflow Plate Logo
static const uint8_t PROGMEM logo[] = {
  0x00, 0x00, 0x00, 0x01, 0x00, 0x00, 0x00, 0x00, 0x00, 0x00, 0x00, 0x00, 0x00, 0x00, 0x00, 0x00,
  0x00, 0x00, 0x00, 0x01, 0x80, 0x00, 0x00, 0x00, 0x00, 0x00, 0x1f, 0x00, 0x00, 0x00, 0x00, 0x00,
  0x00, 0x00, 0x00, 0x01, 0x80, 0x00, 0x00, 0x1f, 0xc0, 0x00, 0x31, 0x80, 0x00, 0x00, 0x00, 0x00,
  0x1f, 0xe0, 0x03, 0x01, 0x80, 0x00, 0x00, 0x30, 0x70, 0x00, 0x21, 0x80, 0x00, 0x00, 0x00, 0x00,
  0x10, 0x20, 0x03, 0x00, 0xc7, 0x80, 0x00, 0x20, 0x18, 0xf0, 0x61, 0x80, 0x00, 0x00, 0x00, 0x00,
  0x18, 0x00, 0x03, 0x3e, 0xcc, 0xc0, 0xc0, 0x04, 0x19, 0x98, 0x61, 0x80, 0x00, 0x00, 0x00, 0x00,
  0x1c, 0x01, 0xf3, 0x77, 0xd8, 0xc7, 0xe0, 0x06, 0x33, 0x18, 0x61, 0x8f, 0x88, 0x00, 0x00, 0x00,
  0x06, 0x03, 0x3b, 0x61, 0xd0, 0xc6, 0x00, 0x07, 0xe2, 0x18, 0x61, 0x98, 0xd8, 0x04, 0x00, 0x00,
  0x01, 0xc6, 0x0b, 0x60, 0xd9, 0x86, 0x00, 0x06, 0x03, 0x30, 0xff, 0xb0, 0x78, 0x66, 0x00, 0x00,
  0x40, 0xe4, 0x0f, 0x60, 0xdf, 0x06, 0x00, 0x07, 0x03, 0xe0, 0x31, 0xe0, 0x78, 0x62, 0x00, 0x00,
  0x40, 0x3c, 0x0f, 0x61, 0xd8, 0x06, 0x00, 0x07, 0x83, 0x00, 0x31, 0xe0, 0x78, 0x63, 0x00, 0x00,
  0x60, 0x36, 0x1b, 0x63, 0xc8, 0x02, 0x00, 0x02, 0xc1, 0x00, 0x18, 0xb0, 0xcc, 0xe2, 0x00, 0x00,
  0x30, 0x33, 0x3b, 0x36, 0x4e, 0x03, 0x00, 0x02, 0x61, 0xc0, 0x0c, 0x99, 0xcd, 0xfe, 0x00, 0x00,
  0x0f, 0xe1, 0xe1, 0x3c, 0x03, 0xf3, 0x00, 0x02, 0x38, 0x7e, 0x0c, 0x8f, 0x07, 0x9c, 0x00, 0x00,
  0x00, 0x00, 0x00, 0x00, 0x00, 0x00, 0x00, 0x00, 0x08, 0x00, 0x00, 0x00, 0x00, 0x00, 0x00, 0x00,
  0x00, 0x00, 0x00, 0x18, 0x00, 0x00, 0x00, 0x00, 0x00, 0x00, 0x00, 0x00, 0x00, 0x00, 0x00, 0x00,
  0x7f, 0x84, 0x00, 0x18, 0x00, 0x00, 0x00, 0x00, 0x00, 0x00, 0x00, 0x00, 0x00, 0x00, 0x00, 0x00,
  0xc0, 0xe4, 0x00, 0x18, 0x38, 0x00, 0x00, 0x00, 0x00, 0x00, 0x00, 0x00, 0x00, 0x00, 0x00, 0x00,
  0x04, 0x3c, 0x3c, 0x18, 0x6c, 0x00, 0x00, 0x00, 0x00, 0x00, 0x00, 0x00, 0x00, 0x00, 0x00, 0x00,
  0x04, 0x1e, 0x06, 0x7f, 0xc6, 0x00, 0x00, 0x00, 0x00, 0x00, 0x00, 0x00, 0x00, 0x00, 0x00, 0x00,
  0x04, 0x3e, 0x03, 0x18, 0x86, 0x00, 0x00, 0x00, 0x00, 0x00, 0x00, 0x00, 0x00, 0x00, 0x00, 0x00,
  0x04, 0x36, 0x7f, 0x19, 0x8c, 0x00, 0x00, 0x00, 0x00, 0x00, 0x00, 0x00, 0x00, 0x00, 0x00, 0x00,
  0x07, 0xe6, 0xc7, 0x19, 0xf8, 0x00, 0x00, 0x00, 0x00, 0x00, 0x00, 0x00, 0x00, 0x00, 0x00, 0x00,
  0x06, 0x07, 0x83, 0x18, 0x80, 0x00, 0x00, 0x00, 0x00, 0x00, 0x00, 0x00, 0x00, 0x00, 0x00, 0x00,
  0x06, 0x07, 0x81, 0x18, 0xc0, 0x00, 0x00, 0x00, 0x00, 0x00, 0x00, 0x00, 0x00, 0x00, 0x00, 0x00,
  0x06, 0x06, 0xc3, 0x98, 0x70, 0x00, 0x00, 0x00, 0x00, 0x00, 0x00, 0x00, 0x00, 0x00, 0x00, 0x00,
  0x02, 0x04, 0x7e, 0x08, 0x3f, 0x80, 0x00, 0x00, 0x00, 0x00, 0x00, 0x00, 0x00, 0x00, 0x00, 0x00
};
static const uint8_t logo_width = 128;
static const uint8_t logo_height = 27;

//Heating Animation
static const uint8_t PROGMEM heat_animate[] = {
  0b00000001, 0b00000000,
  0b00000001, 0b10000000,
  0b00000001, 0b10000000,
  0b00000001, 0b01000000,
  0b00000010, 0b01000000,
  0b00100010, 0b01000100,
  0b00100100, 0b00100100,
  0b01010101, 0b00100110,
  0b01001001, 0b10010110,
  0b10000010, 0b10001001,
  0b10100100, 0b01000001,
  0b10011000, 0b01010010,
  0b01000100, 0b01100010,
  0b00100011, 0b10000100,
  0b00011000, 0b00011000,
  0b00000111, 0b11100000
};
static const uint8_t heat_animate_width = 16;
static const uint8_t heat_animate_height = 16;

//Tick
static const uint8_t PROGMEM tick[] = {
  0b00000000, 0b00000100,
  0b00000000, 0b00001010,
  0b00000000, 0b00010101,
  0b00000000, 0b00101010,
  0b00000000, 0b01010100,
  0b00000000, 0b10101000,
  0b00000001, 0b01010000,
  0b00100010, 0b10100000,
  0b01010101, 0b01000000,
  0b10101010, 0b10000000,
  0b01010101, 0b00000000,
  0b00101010, 0b00000000,
  0b00010100, 0b00000000,
  0b00001000, 0b00000000,
  0b01111111, 0b11100000
};
static const uint8_t tick_width = 16;
static const uint8_t tick_height = 15;

void setup() {

  //Pin Direction control
  pinMode(mosfet,OUTPUT);
  digitalWrite(mosfet,LOW);
  pinMode(temp,INPUT);
  pinMode(vcc,INPUT);

  upButton.attach(upsw);
  upButton.setPressedState(LOW);
  upButton.interval(10);

  downButton.attach(dnsw);
  downButton.setPressedState(LOW);
  downButton.interval(10);

  //Pull saved values from EEPROM
  maxTempIndex = EEPROM.read(tempIndexAddr) % sizeof(maxTempArray);

  //Enable Fast PWM with no prescaler
  //TCCR2A = _BV(COM2A1) | _BV(COM2B1) | _BV(WGM21) | _BV(WGM20);
  //TCCR2B = _BV(CS20);

  //Start-up Diplay
  display.begin(SSD1306_SWITCHCAPVCC, SCREEN_ADDRESS);
  display.clearDisplay();
  display.setTextSize(1);
  display.setTextColor(SSD1306_WHITE);
  display.setCursor(0,0);
  display.drawBitmap(0, 0, logo, logo_width, logo_height, SSD1306_WHITE);
  display.setCursor(80,16);
  display.print(F("S/W V"));
  display.print(sw, 1);
  display.setCursor(80,24);
  display.print(F("H/W V"));
  display.print(hw, 1);
  display.display();
  delay(3000);

  //Go to main menu
  main_menu();
}

void main_menu() {

  int x = 0;  //Display change counter
  int y = 200; //Display change max (modulused below)
  while(1) {
    upButton.update();
    downButton.update();
    analogWrite(mosfet,0); //Ensure MOSFET off
    display.clearDisplay();
    display.setTextSize(1);
    display.drawRoundRect( 0, 0, 83, 32, 2, SSD1306_WHITE);

    //Button Logic
    if(downButton.pressed() || upButton.pressed()) { //If either button pressed
      delay(100);
      //upButton.update();
      //downButton.update();
      if(downButton.pressed() && upButton.pressed()) { //If both buttons pressed
        if(!heat(maxTempArray[maxTempIndex])) {
          cancelledPB();
          main_menu();
        }
        else {
          coolDown();
          completed();
          main_menu();
        }
      }
      if(upButton.pressed() && maxTempIndex < sizeof(maxTempArray) - 1) { //If upper button pressed
        maxTempIndex++;
        EEPROM.update(tempIndexAddr, maxTempIndex);
      }
      if(downButton.pressed() && maxTempIndex > 0) { //If lower button pressed
        maxTempIndex--;
        EEPROM.update(tempIndexAddr, maxTempIndex);
      }
    }

    //Change Display (left-side)
    if( x < (y * 0.5)) {
      display.setCursor(3,4);
      display.print(F("PRESS BUTTONS"));
      display.drawLine( 3, 12, 79, 12, SSD1306_WHITE);
      display.setCursor(3,14);
      display.print(F(" Change  MAX"));
      display.setCursor(3,22);
      display.print(F(" Temperature"));
    }
    else {
      display.setCursor(3,4);
      display.print(F("HOLD  BUTTONS"));
      display.drawLine( 3, 12, 79, 12, SSD1306_WHITE );
      display.setCursor(3,18);
      display.print(F("Begin Heating"));
    }
    x = ( x + 1 ) % y; //Display change increment and modulus

    //Update Display (right-side)
    display.setCursor(95,6);
    display.print(F("TEMP"));
    display.setCursor(95,18);
    display.print(maxTempArray[maxTempIndex]);
    display.print(F("C"));
    display.display();
  }
}

bool heat(byte maxTemp) {
  //Heating Display
  display.clearDisplay();
  display.setTextSize(2);
  display.setCursor(22,4);
  display.print(F("HEATING"));
  display.setTextSize(1);
  display.setCursor(52,24);
  display.print(maxTemp);
  display.print(F("C"));
  display.display();
  delay(3000);

  //Heater Control Variables
  /*  Heater follows industry reflow graph. Slow build-up to 'warmUp' temp. Rapid ascent
   *  to 'maxTemp'. Then descent to room temperature.
   */
  //byte maxTemp; //Declared in function call
  byte maxPWM = 0.70 * maxTemp; //Temperatures (in PWM / 255) influenced by paste temperature
  byte warmUpTemp = 0.75 * maxTemp;
  byte warmUpPWM = 0.72 * warmUpTemp;
  float t; //Used to store current temperature
  float v; //Used to store current voltage
  byte pwmVal = 0; //PWM Value applied to MOSFET
  unsigned long eTime = (millis() / 1000) + (8*60); //Used to store the end time of the heating process, limited to 8 mins

  //Other control variables
  int x = 0;  //Heat Animate Counter
  int y = 80; //Heat Animate max (modulused below)

  while(1) {

    upButton.update();
    downButton.update();

    //Button Control
    if(downButton.pressed() || upButton.pressed()) {
      analogWrite(mosfet, 0);
      return 0;
    }

    //Check Heating not taken more than 8 minutes
    if(millis() / 1000 > eTime) {
      analogWrite(mosfet, 0);
      cancelledTimer();
    }

    //Measure Values
    t = getTemp();
    v = getVolts();
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
RapierXbox, 2023-10-12:
Is the script the same?

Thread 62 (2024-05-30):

New (inofficial) Discord server following mass-deletion and spam

gilex-dev, 2024-05-30:
Since the original "Solder Reflow Plates" discord server linked to on the [startpage](https://github.com/AfterEarthLTD/Solder-Reflow-Plate/blob/66f299ce4258712346cad4ebd1d9e6fde2b60712/README.md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) got griefed on 30.05.2024 (it had no active admin) and development on this repository has stopped, a new discord server has been created to continue development and discussions: https://discord.gg/B8SbEema

Furthermore, an archive was created to preserve most messages from the old server: https://mikoinspace.github.io/SRPARCHIVE/

antoineok, 2024-06-09:
#61

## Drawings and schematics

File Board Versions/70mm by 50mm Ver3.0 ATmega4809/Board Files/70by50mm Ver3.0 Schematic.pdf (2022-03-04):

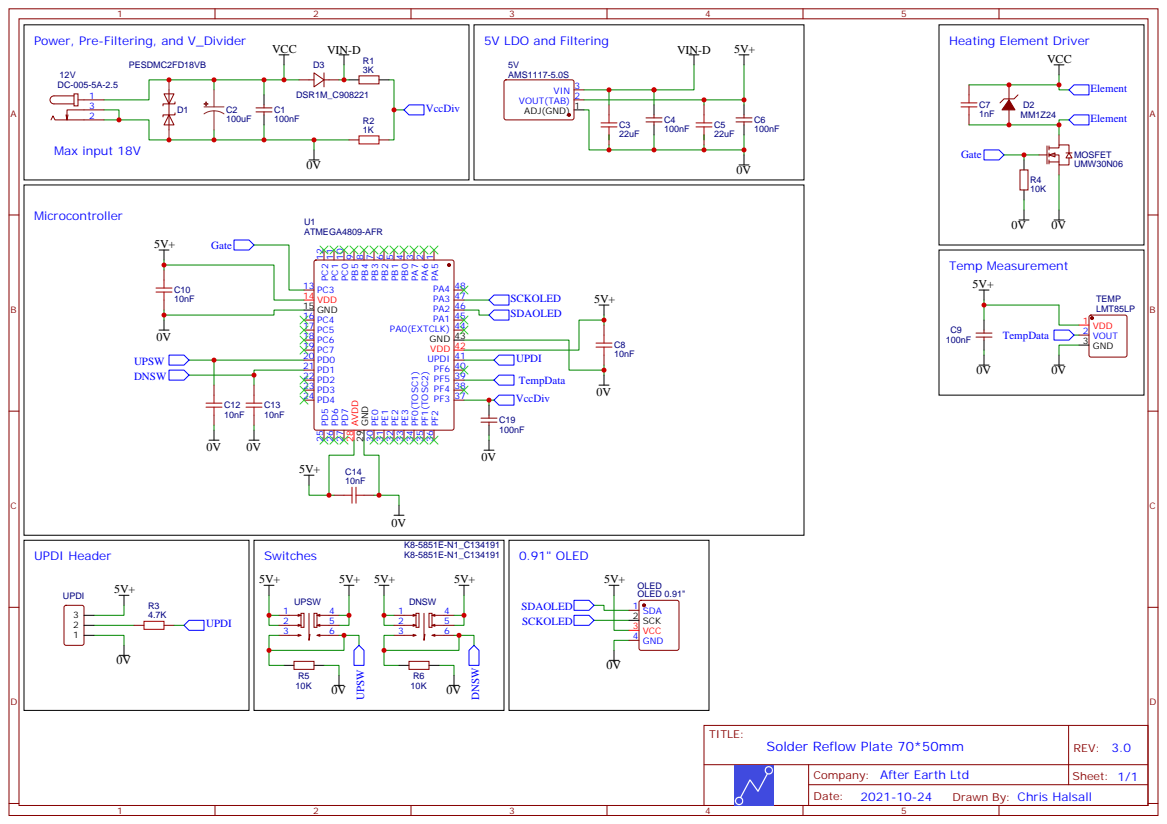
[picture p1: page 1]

Power, Pre-Filtering, and V_Divider

Company: After Earth Ltd

Drawn By: Chris Halsall

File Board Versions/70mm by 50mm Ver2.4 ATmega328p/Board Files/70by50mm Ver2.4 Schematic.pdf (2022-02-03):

## Max input 18V

5V+ 5V LDO and Filtering | Heating Element Driver

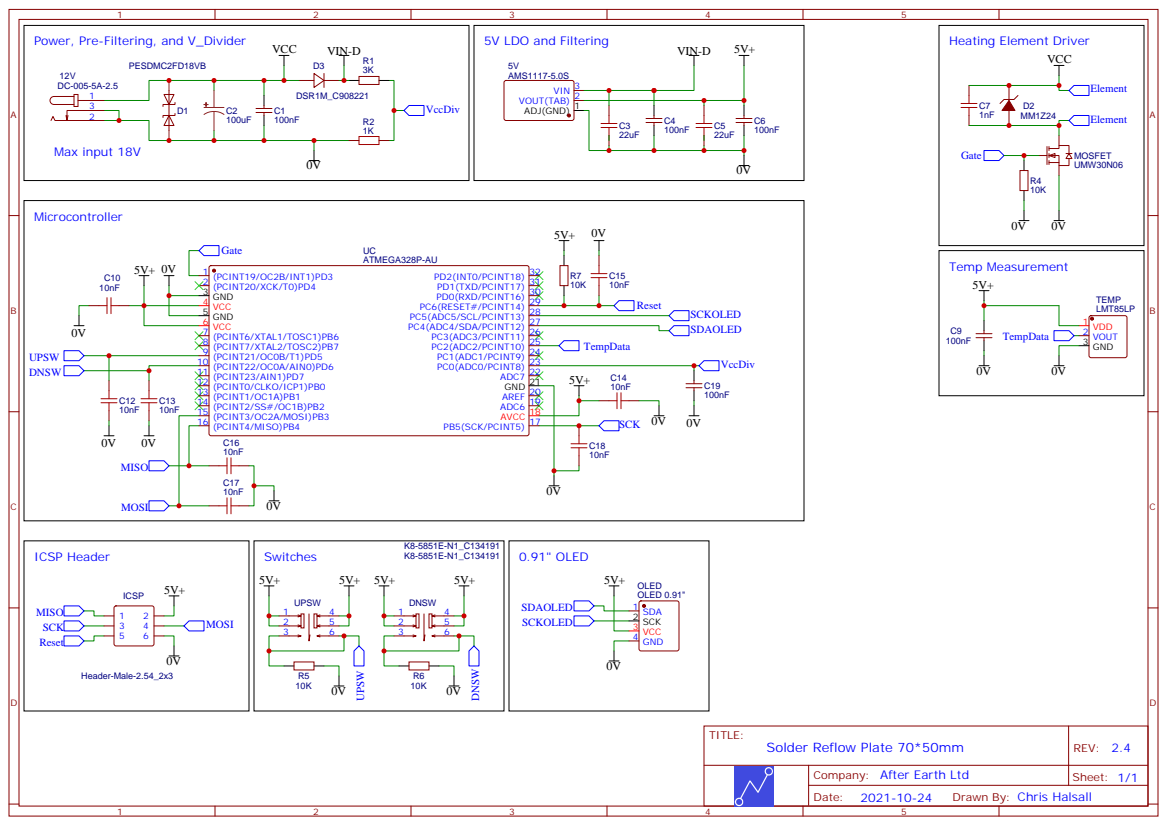
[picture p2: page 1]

Power, Pre-Filtering, and V_Divider

Company: After Earth Ltd

Drawn By: Chris Halsall

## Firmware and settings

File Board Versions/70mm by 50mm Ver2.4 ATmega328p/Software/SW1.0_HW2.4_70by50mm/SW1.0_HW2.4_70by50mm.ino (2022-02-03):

/* Solder Reflow Plate Sketch
 *  H/W - Ver 2.4
 *  S/W - Ver 1.0
 *  by Chris Halsall     */

/* To prepare
 * 1) Install MiniCore in additional boards; (copy into File->Preferences->Additional Boards Manager URLs)
 *     https://mcudude.github.io/MiniCore/package_MCUdude_MiniCore_index.json
 * 2) Then add MiniCore by searching and installing (Tools->Board->Board Manager)
 * 3) Install Adafruit_GFX and Adafruit_SSD1306 libraries (Tools->Manage Libraries)
 */

/* To program
 *  1) Select the following settings under (Tools)
 *      Board->Minicore->Atmega328 
 *      Clock->Internal 8MHz
 *      BOD->BOD 2.7V
 *      EEPROM->EEPROM retained
 *      Compiler LTO->LTO Disabled
 *      Variant->328P / 328PA
 *      Bootloader->No bootloader
 *  2) Set programmer of choice, e.g.'Arduino as ISP (MiniCore)', 'USB ASP', etc, and set correct port.
 *  3) Burn bootloader (to set fuses correctly)
 *  4) Compile and upload
 */

#include <SPI.h>
#include <Adafruit_GFX.h>
#include <Adafruit_SSD1306.h>
#include <EEPROM.h>

//Version Definitions
static const PROGMEM float hw = 2.4;
static const PROGMEM float sw = 1.0;

//Screen Definitions
#define SCREEN_WIDTH 128
#define SCREEN_HEIGHT 32
#define SCREEN_ADDRESS 0x3C   //I2C Address
Adafruit_SSD1306 display(SCREEN_WIDTH, SCREEN_HEIGHT, &Wire, -1); //Create Display

//Pin Definitions
#define mosfet 3
#define upsw 6
#define dnsw 5
#define temp 16   //A2
#define vcc 14    //A0

//Temperature Info
byte maxTempArray[] = { 140, 150, 160, 170, 180 };
byte maxTempIndex = 0;
byte tempIndexAddr = 1;

//Voltage Measurement Info
float vConvert = 52.00;
float vMin = 10.50;

//Solder Reflow Plate Logo
static const uint8_t PROGMEM logo[] = { 
  0x00, 0x00, 0x00, 0x01, 0x00, 0x00, 0x00, 0x00, 0x00, 0x00, 0x00, 0x00, 0x00, 0x00, 0x00, 0x00, 
  0x00, 0x00, 0x00, 0x01, 0x80, 0x00, 0x00, 0x00, 0x00, 0x00, 0x1f, 0x00, 0x00, 0x00, 0x00, 0x00, 
  0x00, 0x00, 0x00, 0x01, 0x80, 0x00, 0x00, 0x1f, 0xc0, 0x00, 0x31, 0x80, 0x00, 0x00, 0x00, 0x00, 
  0x1f, 0xe0, 0x03, 0x01, 0x80, 0x00, 0x00, 0x30, 0x70, 0x00, 0x21, 0x80, 0x00, 0x00, 0x00, 0x00, 
  0x10, 0x20, 0x03, 0x00, 0xc7, 0x80, 0x00, 0x20, 0x18, 0xf0, 0x61, 0x80, 0x00, 0x00, 0x00, 0x00, 
  0x18, 0x00, 0x03, 0x3e, 0xcc, 0xc0, 0xc0, 0x04, 0x19, 0x98, 0x61, 0x80, 0x00, 0x00, 0x00, 0x00, 
  0x1c, 0x01, 0xf3, 0x77, 0xd8, 0xc7, 0xe0, 0x06, 0x33, 0x18, 0x61, 0x8f, 0x88, 0x00, 0x00, 0x00, 
  0x06, 0x03, 0x3b, 0x61, 0xd0, 0xc6, 0x00, 0x07, 0xe2, 0x18, 0x61, 0x98, 0xd8, 0x04, 0x00, 0x00, 
  0x01, 0xc6, 0x0b, 0x60, 0xd9, 0x86, 0x00, 0x06, 0x03, 0x30, 0xff, 0xb0, 0x78, 0x66, 0x00, 0x00, 
  0x40, 0xe4, 0x0f, 0x60, 0xdf, 0x06, 0x00, 0x07, 0x03, 0xe0, 0x31, 0xe0, 0x78, 0x62, 0x00, 0x00, 
  0x40, 0x3c, 0x0f, 0x61, 0xd8, 0x06, 0x00, 0x07, 0x83, 0x00, 0x31, 0xe0, 0x78, 0x63, 0x00, 0x00, 
  0x60, 0x36, 0x1b, 0x63, 0xc8, 0x02, 0x00, 0x02, 0xc1, 0x00, 0x18, 0xb0, 0xcc, 0xe2, 0x00, 0x00, 
  0x30, 0x33, 0x3b, 0x36, 0x4e, 0x03, 0x00, 0x02, 0x61, 0xc0, 0x0c, 0x99, 0xcd, 0xfe, 0x00, 0x00, 
  0x0f, 0xe1, 0xe1, 0x3c, 0x03, 0xf3, 0x00, 0x02, 0x38, 0x7e, 0x0c, 0x8f, 0x07, 0x9c, 0x00, 0x00, 
  0x00, 0x00, 0x00, 0x00, 0x00, 0x00, 0x00, 0x00, 0x08, 0x00, 0x00, 0x00, 0x00, 0x00, 0x00, 0x00, 
  0x00, 0x00, 0x00, 0x18, 0x00, 0x00, 0x00, 0x00, 0x00, 0x00, 0x00, 0x00, 0x00, 0x00, 0x00, 0x00, 
  0x7f, 0x84, 0x00, 0x18, 0x00, 0x00, 0x00, 0x00, 0x00, 0x00, 0x00, 0x00, 0x00, 0x00, 0x00, 0x00, 
  0xc0, 0xe4, 0x00, 0x18, 0x38, 0x00, 0x00, 0x00, 0x00, 0x00, 0x00, 0x00, 0x00, 0x00, 0x00, 0x00, 
  0x04, 0x3c, 0x3c, 0x18, 0x6c, 0x00, 0x00, 0x00, 0x00, 0x00, 0x00, 0x00, 0x00, 0x00, 0x00, 0x00, 
  0x04, 0x1e, 0x06, 0x7f, 0xc6, 0x00, 0x00, 0x00, 0x00, 0x00, 0x00, 0x00, 0x00, 0x00, 0x00, 0x00, 
  0x04, 0x3e, 0x03, 0x18, 0x86, 0x00, 0x00, 0x00, 0x00, 0x00, 0x00, 0x00, 0x00, 0x00, 0x00, 0x00, 
  0x04, 0x36, 0x7f, 0x19, 0x8c, 0x00, 0x00, 0x00, 0x00, 0x00, 0x00, 0x00, 0x00, 0x00, 0x00, 0x00, 
  0x07, 0xe6, 0xc7, 0x19, 0xf8, 0x00, 0x00, 0x00, 0x00, 0x00, 0x00, 0x00, 0x00, 0x00, 0x00, 0x00, 
  0x06, 0x07, 0x83, 0x18, 0x80, 0x00, 0x00, 0x00, 0x00, 0x00, 0x00, 0x00, 0x00, 0x00, 0x00, 0x00, 
  0x06, 0x07, 0x81, 0x18, 0xc0, 0x00, 0x00, 0x00, 0x00, 0x00, 0x00, 0x00, 0x00, 0x00, 0x00, 0x00, 
  0x06, 0x06, 0xc3, 0x98, 0x70, 0x00, 0x00, 0x00, 0x00, 0x00, 0x00, 0x00, 0x00, 0x00, 0x00, 0x00, 
  0x02, 0x04, 0x7e, 0x08, 0x3f, 0x80, 0x00, 0x00, 0x00, 0x00, 0x00, 0x00, 0x00, 0x00, 0x00, 0x00
};
static const uint8_t logo_width = 128;
static const uint8_t logo_height = 27;

//Heating Animation
static const uint8_t PROGMEM heat_animate[] = {
  0b00000001, 0b00000000,
  0b00000001, 0b10000000,
  0b00000001, 0b10000000,
  0b00000001, 0b01000000,
  0b00000010, 0b01000000,
  0b00100010, 0b01000100,
  0b00100100, 0b00100100,
  0b01010101, 0b00100110,
  0b01001001, 0b10010110,
  0b10000010, 0b10001001,
  0b10100100, 0b01000001,
  0b10011000, 0b01010010,
  0b01000100, 0b01100010,
  0b00100011, 0b10000100,
  0b00011000, 0b00011000,
  0b00000111, 0b11100000
};
static const uint8_t heat_animate_width = 16;
static const uint8_t heat_animate_height = 16;

//Tick
static const uint8_t PROGMEM tick[] = {
  0b00000000, 0b00000100,
  0b00000000, 0b00001010,
  0b00000000, 0b00010101,
  0b00000000, 0b00101010,
  0b00000000, 0b01010100,
  0b00000000, 0b10101000,
  0b00000001, 0b01010000,
  0b00100010, 0b10100000,
  0b01010101, 0b01000000,
  0b10101010, 0b10000000,
  0b01010101, 0b00000000,
  0b00101010, 0b00000000,
  0b00010100, 0b00000000,
  0b00001000, 0b00000000,
  0b01111111, 0b11100000
};
static const uint8_t tick_width = 16;
static const uint8_t tick_height = 15;

void setup() {
  
  //Pin Direction control
  pinMode(mosfet,OUTPUT);
  digitalWrite(mosfet,LOW);
  pinMode(upsw,INPUT);
  pinMode(dnsw,INPUT);
  pinMode(temp,INPUT);
  pinMode(vcc,INPUT);

  //Pull saved values from EEPROM
  maxTempIndex = EEPROM.read(tempIndexAddr) % sizeof(maxTempArray);

  //Enable Fast PWM with no prescaler
  TCCR2A = _BV(COM2A1) | _BV(COM2B1) | _BV(WGM21) | _BV(WGM20);
  TCCR2B = _BV(CS20);

  //Start-up Diplay
  display.begin(SSD1306_SWITCHCAPVCC, SCREEN_ADDRESS);
  display.clearDisplay();
  display.setTextSize(1);
  display.setTextColor(SSD1306_WHITE);
  display.setCursor(0,0);
  display.drawBitmap(0, 0, logo, logo_width, logo_height, SSD1306_WHITE);
  display.setCursor(80,16);
  display.print(F("S/W V"));
  display.print(sw, 1);
  display.setCursor(80,24);
  display.print(F("H/W V"));
  display.print(hw, 1);
  display.display();
  delay(3000);

  //Go to main menu
  main_menu();
}

void main_menu() {
  //Debounce
  while(!digitalRead(upsw) || !digitalRead(dnsw)) {  }
  
  int x = 0;  //Display change counter
  int y = 200; //Display change max (modulused below)
  while(1) {
    analogWrite(mosfet,0); //Ensure MOSFET off
    display.clearDisplay();
    display.setTextSize(1);
    display.drawRoundRect( 0, 0, 83, 32, 2, SSD1306_WHITE);

    //Button Logic
    if(!digitalRead(upsw) || !digitalRead(dnsw)) { //If either button pressed
      delay(100);
      if(!digitalRead(upsw) && !digitalRead(dnsw)) { //If both buttons pressed
        if(!heat(maxTempArray[maxTempIndex])) {
          cancelledPB();
          main_menu();
        }
        else {
          coolDown();
          completed();
          main_menu();
        }
      }
      if(!digitalRead(upsw) && maxTempIndex < sizeof(maxTempArray) - 1) { //If upper button pressed
        maxTempIndex++;
        EEPROM.update(tempIndexAddr, maxTempIndex);
      }
      if(!digitalRead(dnsw) && maxTempIndex > 0) { //If lower button pressed
        maxTempIndex--;
        EEPROM.update(tempIndexAddr, maxTempIndex);
      }
    }

    //Change Display (left-side)
    if( x < (y * 0.5)) {
      display.setCursor(3,4);
      display.print(F("PRESS BUTTONS"));
      display.drawLine( 3, 12, 79, 12, SSD1306_WHITE); 
      display.setCursor(3,14);
      display.print(F(" Change  MAX"));
      display.setCursor(3,22);
      display.print(F(" Temperature"));
    }
    else {
      display.setCursor(3,4);
      display.print(F("HOLD  BUTTONS"));
      display.drawLine( 3, 12, 79, 12, SSD1306_WHITE ); 
      display.setCursor(3,18);
      display.print(F("Begin Heating"));
    }
    x = ( x + 1 ) % y; //Display change increment and modulus
    
    //Update Display (right-side)
    display.setCursor(95,6);
    display.print(F("TEMP"));
    display.setCursor(95,18);
    display.print(maxTempArray[maxTempIndex]);
    display.print(F("C"));
    display.display();
  }
}

bool heat(byte maxTemp) {
  //Debounce
  while(!digitalRead(upsw) || !digitalRead(dnsw)) {  }
  
  //Heating Display
  display.clearDisplay();
  display.setTextSize(2);
  display.setCursor(22,4);
  display.print(F("HEATING"));
  display.setTextSize(1);
  display.setCursor(52,24);
  display.print(maxTemp);
  display.print(F("C"));
  display.display();
  delay(3000);

  //Heater Control Variables
  /*  Heater follows industry reflow graph. Slow build-up to 'warmUp' temp. Rapid ascent
   *  to 'maxTemp'. Then descent to room temperature. 
   */
  //byte maxTemp; //Declared in function call
  byte maxPWM = 0.70 * maxTemp; //Temperatures (in PWM / 255) influenced by paste temperature
  byte warmUpTemp = 0.75 * maxTemp;
  byte warmUpPWM = 0.72 * warmUpTemp;
  float t; //Used to store current temperature
  float v; //Used to store current voltage
  byte pwmVal = 0; //PWM Value applied to MOSFET
  unsigned long eTime = (millis() / 1000) + (8*60); //Used to store the end time of the heating process, limited to 8 mins

  //Other control variables
  int x = 0;  //Heat Animate Counter
  int y = 80; //Heat Animate max (modulused below)
  
  while(1) {
    //Button Control
    if(!digitalRead(upsw) || !digitalRead(dnsw)) {
      analogWrite(mosfet, 0);
      return 0;
    }

    //Check Heating not taken more than 8 minutes
    if(millis() / 1000 > eTime) {
      analogWrite(mosfet, 0);
      cancelledTimer();
    }

    //Measure Values
    t = getTemp();
    v = getVolts();

    //Reflow Profile
    if (t < warmUpTemp) { //Warm Up Section
      if (pwmVal != warmUpPWM) { pwmVal++; } //Slowly ramp to desired PWM Value
      if (v < vMin && pwmVal > 1) { pwmVal = pwmVal - 2; } //Reduce PWM Value if V drops too low but not unless it is still above 1 (avoid overflow/underflow)
    }
    else if (t < maxTemp) { //Push to maximum temp
      if (pwmVal != maxPWM) { pwmVal++; } //Slowly ramp to desired PWM Value
      if (v < vMin && pwmVal > 1) { pwmVal = pwmVal - 2; } //Reduce PWM Value if V drops too low but not unless it is still above 1 (avoid overflow/underflow)
    }
    else { //Heating Complete, return
      analogWrite(mosfet, 0);
      break;
    }
    if (pwmVal > maxPWM ) { pwmVal = maxPWM; } //Catch incase of runaway 

    //MOSFET Control
    analogWrite(mosfet, pwmVal);

    //Heat Animate Control
    display.clearDisplay();
    display.drawBitmap( 0, 3, heat_animate, heat_animate_width, heat_animate_height, SSD1306_WHITE);
    display.drawBitmap( 112, 3, heat_animate, heat_animate_width, heat_animate_height, SSD1306_WHITE);
    display.fillRect( 0, 3, heat_animate_width, heat_animate_height * (y - x) / y, SSD1306_BLACK);
    display.fillRect( 112, 3, heat_animate_width, heat_animate_height * (y - x) / y, SSD1306_BLACK);
    x = ( x + 1 ) % y; //Heat animate increment and modulus

    //Update display
    display.setTextSize(2);
    display.setCursor(22,4);
    display.print(F("HEATING"));
    display.setTextSize(1);
    display.setCursor(20,24);
    display.print(F("~"));
    display.print(v,1);
    display.print(F("V"));
    if( t >= 100 )      { display.setCursor(78,24); }
    else if ( t >= 10 ) { display.setCursor(81,24); }
    else                { display.setCursor(84,24); }
    display.print(F("~"));
    display.print(t,0);
    display.print(F("C"));
    display.display();
  }
}

void cancelledPB() { //Cancelled via push button
  //Debounce
  while(!digitalRead(upsw) || !digitalRead(dnsw)) {  }

  //Update Display
  display.clearDisplay();
  display.drawRoundRect( 22, 0, 84, 32, 2, SSD1306_WHITE );
  display.setCursor(25,4);
  display.print(F("  CANCELLED"));
  display.drawLine( 25, 12, 103, 12, SSD1306_WHITE );
  display.setCursor(25,14);
  display.println(" Push button");
  display.setCursor(25,22);
  display.println("  to return");
  display.setTextSize(3);
  display.setCursor(5,4);
  display.print(F("!"));
  display.setTextSize(3);
  display.setCursor(108,4);
  display.print(F("!"));
  display.setTextSize(1);
  display.display();
  delay(50);

  //Wait to return on any button press
  while(digitalRead(upsw) && digitalRead(dnsw)) {  }
}

void cancelledTimer() { //Cancelled via 5 minute Time Limit
  //Debounce
  while(!digitalRead(upsw) || !digitalRead(dnsw)) {  }

  //Initiate Swap Display
  int x = 0;  //Display change counter
  int y = 150; //Display change max (modulused below)

  //Wait to return on any button press
  while(digitalRead(upsw) && digitalRead(dnsw)) {
    //Update Display
    display.clearDisplay();
    display.drawRoundRect( 22, 0, 84, 32, 2, SSD1306_WHITE );
    display.setCursor(25,4);
    display.print(F("  TIMED OUT"));
    display.drawLine( 25, 12, 103, 12, SSD1306_WHITE );

    //Swap Main Text
    if( x < (y * 0.3)) {
      display.setCursor(25,14);
      display.println(" Took longer");
      display.setCursor(25,22);
      display.println(" than 5 mins");
    }
    else if( x < (y * 0.6)) {
      display.setCursor(28,14);
      display.println("Try a higher");
      display.setCursor(25,22);
      display.println(" current PSU");
    }
    else {
      display.setCursor(25,14);
      display.println(" Push button");
      display.setCursor(25,22);
      display.println("  to return");
    }
    x = ( x + 1 ) % y; //Display change increment and modulus
    
    display.setTextSize(3);
    display.setCursor(5,4);
    display.print(F("!"));
    display.setTextSize(3);
    display.setCursor(108,4);
    display.print(F("!"));
    display.setTextSize(1);
    display.display();
    delay(50);
  }
  main_menu();
}

void coolDown() {
  //Debounce
  while(!digitalRead(upsw) || !digitalRead(dnsw)) {  }
  
  float t = getTemp(); //Used to store current temperature
  
  //Wait to return on any button press, or temp below threshold
  while(digitalRead(upsw) && digitalRead(dnsw) && t > 45.00) {
    display.clearDisplay();
    display.drawRoundRect( 22, 0, 84, 32, 2, SSD1306_WHITE );
    display.setCursor(25,4);
    display.print(F("  COOL DOWN"));
    display.drawLine( 25, 12, 103, 12, SSD1306_WHITE );
    display.setCursor(25,14);
    display.println("  Still Hot");
    t = getTemp();
      if( t >= 100 ) { display.setCursor(49,22); }
      else           { display.setCursor(52,22); }
      display.print(F("~"));
      display.print(t,0);
      display.print(F("C"));
    display.setTextSize(3);
    display.setCursor(5,4);
    display.print(F("!"));
    display.setTextSize(3);
    display.setCursor(108,4);
    display.print(F("!"));
    display.setTextSize(1);
    display.display();
  }
}

void completed() {
  //Debounce
  while(!digitalRead(upsw) || !digitalRead(dnsw)) {  }

  //Update Display
  display.clearDisplay();
  display.drawRoundRect( 22, 0, 84, 32, 2, SSD1306_WHITE );
  display.setCursor(25,4);
  display.print(F("  COMPLETED  "));
  display.drawLine( 25, 12, 103, 12, SSD1306_WHITE );
  display.setCursor(25,14);
  display.println(" Push button");
  display.setCursor(25,22);
  display.println("  to return");
  display.drawBitmap( 0, 9, tick, tick_width, tick_height, SSD1306_WHITE);
  display.drawBitmap( 112, 9, tick, tick_width, tick_height, SSD1306_WHITE);
  display.display();

  //Wait to return on any button press
  while(digitalRead(upsw) && digitalRead(dnsw)) {  }
}

float getTemp(){
  float t = 0;
  for (byte i = 0; i < 100; i++){ //Poll temp reading 100 times
    t = t + analogRead(temp);
  }
  return ((t / 100) * -1.46) + 434; //Average, convert to C, and return
}

float getVolts(){
  float v = 0;
  for (byte i = 0; i < 20; i++){ //Poll Voltage reading 20 times
    v = v + analogRead(vcc);
  }
  return v / 20 / vConvert; //Average, convert to V, and return
}

void loop() {
  // Not used
}

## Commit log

2022-02-03 Various Documentation
    Wrote how to build stock board
    Updated links in lots of others
    Wrote Software revisions doc
2022-02-03 Updated
    Fine Tuning Heat Process Code
    Small doc updates
2022-02-03 Board Files
    Added all major board files.
    Updated Sketch heating, removed thickness and limited to 180C.
    [BOM_SRP 70_50mm_Release_2022-02-03.csv, PickAndPlace_SRP 70_50mm_Release_2022-02-03.csv, SRP 70_50mm_Release_2022-02-03.pcbdoc]
2022-02-28 Added EasyEDA Schematic File
2022-03-04 Added docs from Ver3.0 Board based on 4809.
    [BOM_SRP 70_50mm_Release_2022-02-03.csv, BOM_SRP 70_50mm_Release_2022-03-04.csv, PickAndPlace_SRP 70_50mm_Release_2022-02-03.csv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]
2022-03-14 Updated Discord Link & Fixed Pick and Place files.
    -Issue with OLED 0.91" tricking conversion into .csv
    [PickAndPlace_SRP 70_50mm_Release_2022-02-03.csv, PickAndPlace_SRP 70_50mm_Release_2022-03-04.csv]
